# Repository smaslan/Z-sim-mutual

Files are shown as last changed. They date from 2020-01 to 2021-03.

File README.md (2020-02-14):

# Capacitive Reactance Simulator Based on Mutual Inductor

This project is simple simulator of capacitive rectance based on a mutual inductor.
It is just a first proof of concept prototype not inteded for direct production/replication.
See DOC for known issues and more details.

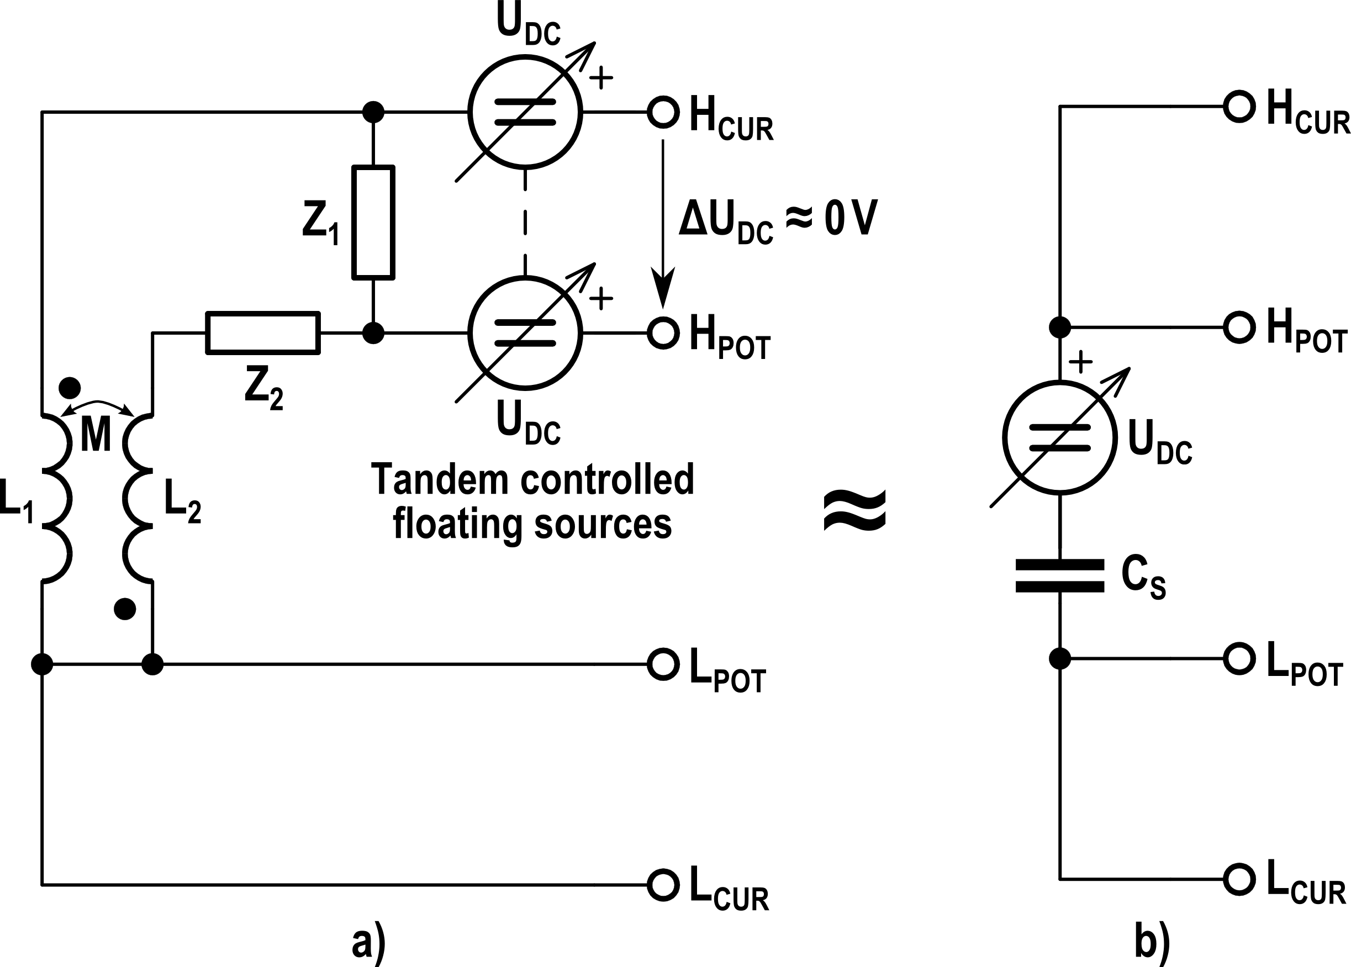
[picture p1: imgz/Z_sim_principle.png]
Z-sim-mutual


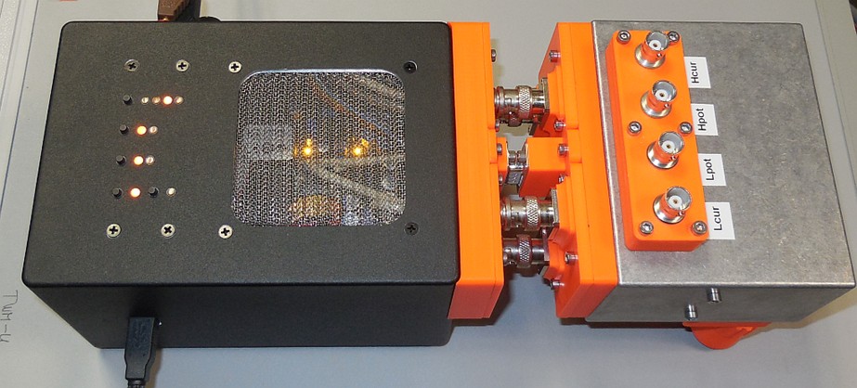
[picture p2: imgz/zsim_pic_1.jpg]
Protoype


## License
The HW design is distributed under [Cern OHL license V1.2](./cern_ohl_v_1_2.pdf). 

## Acknowledgment
Presented standard design was co-developed in scope of the [EMPIR](http://msu.euramet.org/calls.html) 
project [LiBforSecUse (17IND10)](https://www.ptb.de/empir2018/libforsecuse/home/).
The project received funding from the EMPIR programme co-financed by the Participating States 
and from the European Union's Horizon 2020 research and innovation programme.

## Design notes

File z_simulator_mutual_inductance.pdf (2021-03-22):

Mutual inductance based impedance simulator

EMPIR project report: LiBforSecUse, activity A1.1.4

Stanislav Mašláň, smaslan@cmi.cz, Czech Metrology Institute, 2021-03-22

Following document briefly describes experimental design of capacitive reactance simulator based on mutual inductance. Additional details are shown in Imeko paper [3]. The simulator is designed for calibration of battery impedance spectroscopy analysers (EIS).

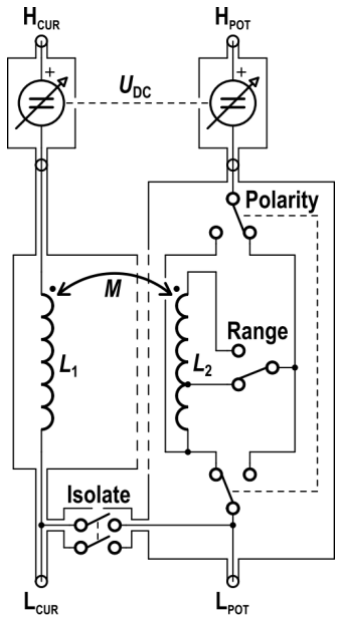
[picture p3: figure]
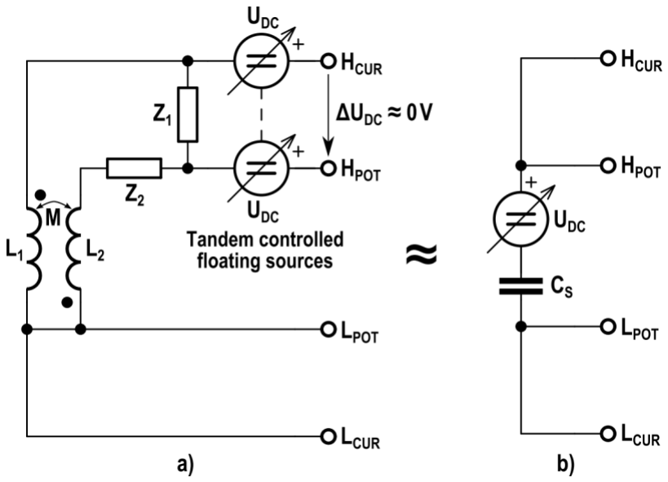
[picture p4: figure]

Figure 1: Principle of capacitance simulator based on mutual inductance (Left), full coaxial connection (Right).

The goal of the design was to achieve large capacitive reactance with simulation of DC bias voltage roughly equal to lithium cell (around 4V). The standard must be able to withstand measurement current at least 1A AC and 1A DC (2.5A peak current in both polarities).
One of the simple ways of simulating reactance is mutual inductor which can be easily designed to exhibit mutual inductances in order of nanohenry to microhenry and to be able to carry high measurement currents. If the secondary winding polarity is inverted, the apparent four terminal impedance will appear as capacitive reactance to the EIS. The basic concept is shown in Figure 1. Impedances Z1 and Z2 can be used to fine tune the apparent impedance, however they are not necessary.

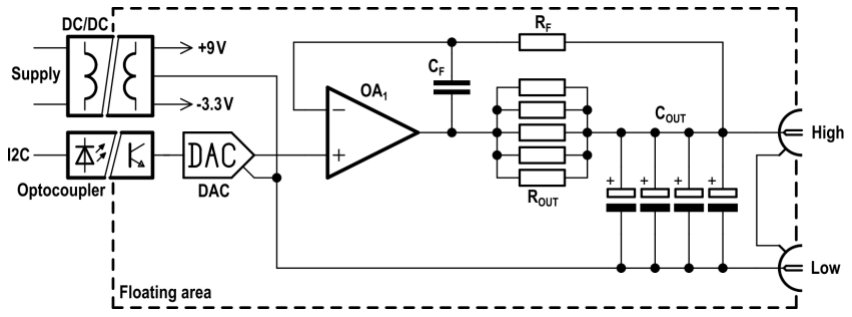
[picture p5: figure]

Figure 2: Principle of DC bias generator.

The challenging part of the design is however introduction of the DC bias voltage. It is not possible to simply insert high power DC source in series with mutual inductor, because its internal impedance would destroy properties of the impedance. It is also not reasonable to insert it just into the potential terminal, because then the EIS meter will see DC voltage between its Hcur and Hpot terminals. It may lead to fail indication or even damage of the EIS. So an alternative solution shown in Figure 1 was chosen. Two tandem controlled sources were used. One, high power floating DC source capable to withstand the measurement current is connected in series with the Hcur terminal. This source does not have to be very accurate. A second floating DC source is placed in series with the Hpot terminal. This source carries almost no current, but should be accurate and low noise. Both sources are set to identical voltage, so the EIS meter will see near zero voltage difference between Hcur and Hpot terminals and at the same time will see necessary DC bias of the impedance.

Design of DC bias source

Circuit design of first prototype is shown in Figure 3 or see GitHub source files [1]. Evidently the only complicated part of the design is the DC bias source. Both DC sources must be floating. For purposes of first prototype this was solved by using DC/DC converters. The current DC bias is supplied from a pair of 9V and 3V3 converters. This asymmetric supply was chosen to minimize power dissipation as the DC voltage range is 0 to 5V and the power opamp OPA548 needs at least some 3V reserve. The DC/DC converters outputs are filtered by low-ESR polymer caps. Care must be taken to not exceed maximum filter capacitance for particular converter to prevent regulator instability. The controlled DC source is based on power opamp OPA548. It is equipped by stabilizing network and the output is filtered by low-ESR capacitors. The opamp feedback is providing low output impedance for low frequencies, whereas the large output capacitance is providing low impedance for higher frequencies. The voltage of this source is generated by 12bit DAC connected via isolated I2C bus. Zero and gain are set by two trimmers. The whole source can be disabled by DC/DC converter enable inputs and in that case a pair of parallel latching relays bypasses the output of the source.

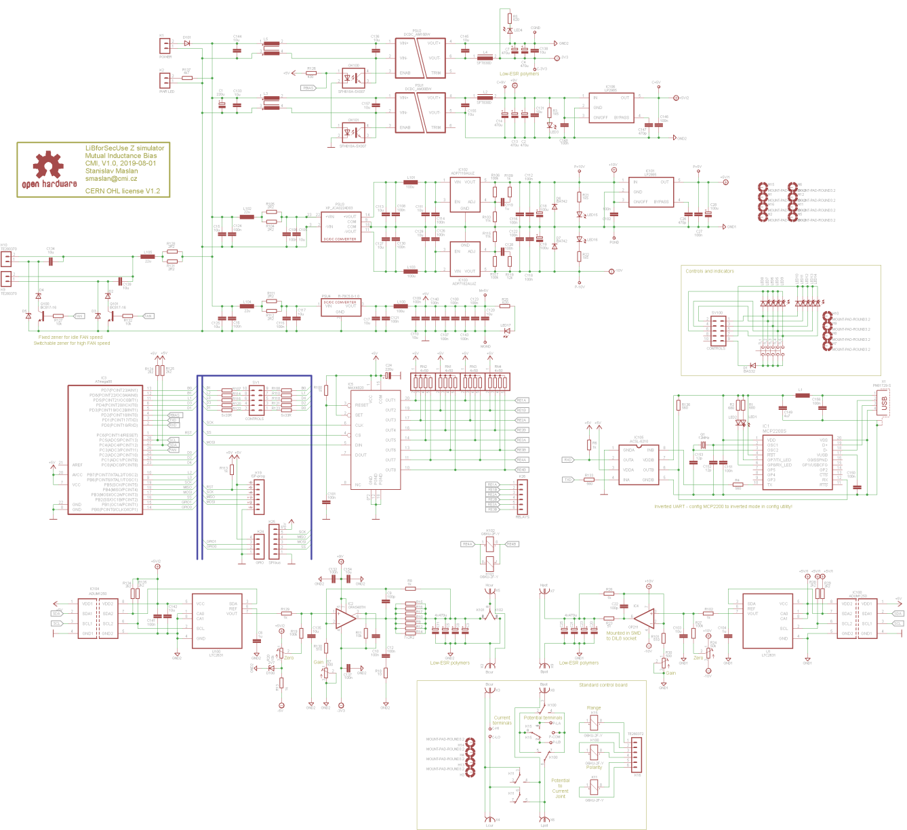
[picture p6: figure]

Figure 3: Circuit diagram of impedance simulator prototype.

The second source inserted to the potential terminals is of similar concept except it is supplied from low noise DC/DC converter with low noise LDO regulators and uses low power opamp OP211. Its output is also equipped by stabilizing network and the opamp and stabilizing network components must be chosen so it is stable with large output capacitance.
The standard itself (mutual inductor) is placed in separate box. It is connected via additional board with few latching relays that enables switching the polarity and range of the mutual inductor.
The whole unit is controlled by microcontroller AVR ATmega88. It is equipped by simple user interface with buttons and LED diodes and also it is connected to USB-UART converter MCP2200 for remote control. Note the MCP2200 is connected via optoisolator which inverts UART polarity, so MCP2200 configuration utility must be used to invert polarity of UART outputs.
The unit contains electronically switchable fan outputs with regulation of speed using Zener diodes. One diode is intended to be used for idle speed and the other switchable for high speed when current path DC bias is enabled.

Construction notes

Board drawings are shown in Figure 4 and Figure 5 and at GitHub [1]. The DC source unit was designed to fit in Hammond die cast box HM-1550F. The power opamp OPA548 is soldered from bottom of the PCB, so its terminals must be bent up from the heatsink. It is screwed to the heatsink which is screwed from bottom of the PCB. The heatsink must be able to cool full power which is up to some 23W, so a fans are intended to be used.
The standard itself was placed to another box Eddyston 26908PSLA together with the relay board. Both boxes are connected via BNC connectors and Cannon 9 connector. The output terminals to the EIS are placed at the standard box. The connection between the two boxes is made using 3D printed components which are also available at GitHub [1]. Note there are no male BNCs with crimping terminals, so a flange types were used and they are connected to the coaxes via brass foil screwed to them.
The mutual inductor itself is constructed as air-core toroid so most of the field is contained. Therefore, it is not affected by near metallic objects and exhibits no significant non-linearities. The winding is made from multifilar rope of copper enamelled wires. 10 wires from the rope are connected in parallel and used as primary. The remaining 10 are connected in series to form secondary. The unit has two ranges, so one range is full 10 loops and the other range is connected to a first tap. The core of the toroid is 3D printed. See GitHub for model.

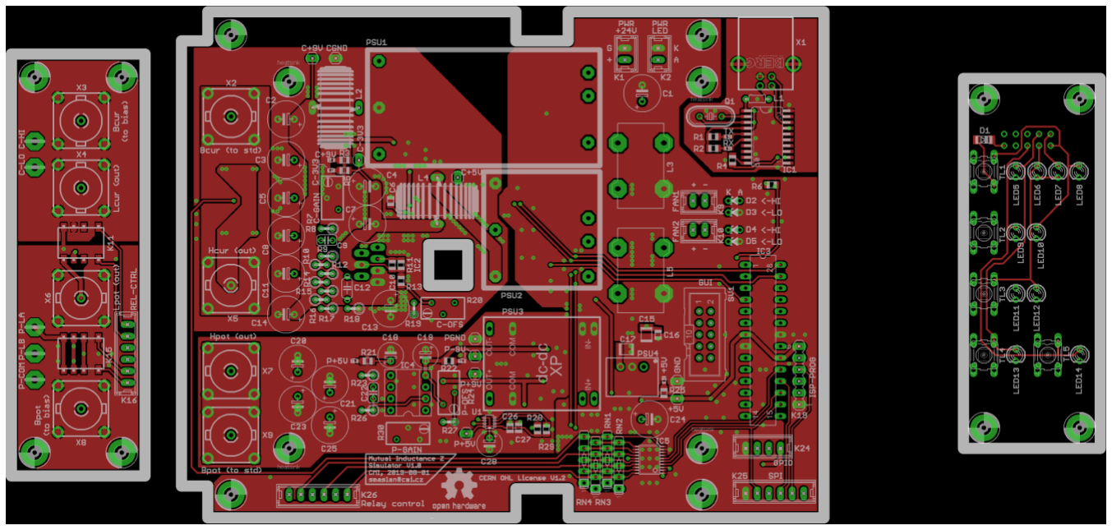
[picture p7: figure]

Figure 4: Top layer of PCB.

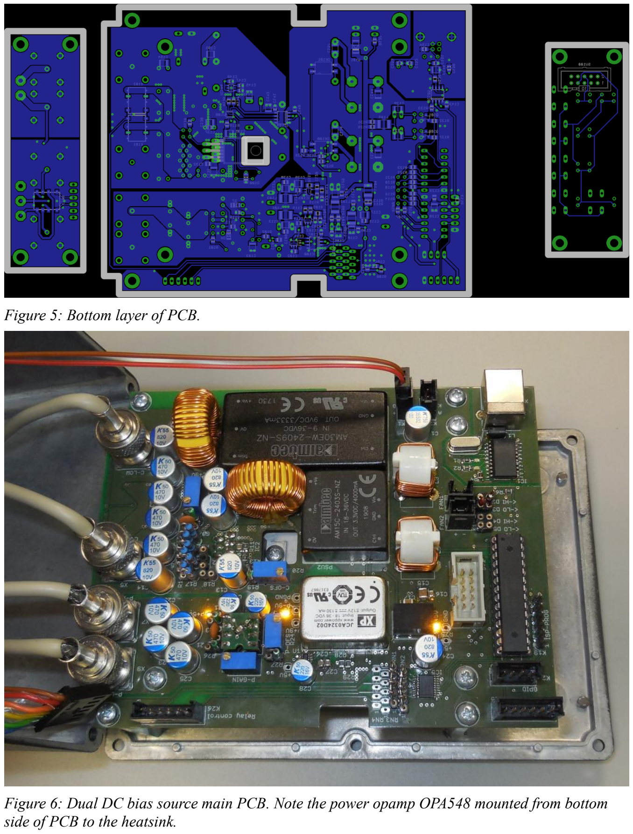
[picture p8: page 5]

Figure 5: Bottom layer of PCB.

Figure 6: Dual DC bias source main PCB. Note the power opamp OPA548 mounted from bottom side of PCB to the heatsink.

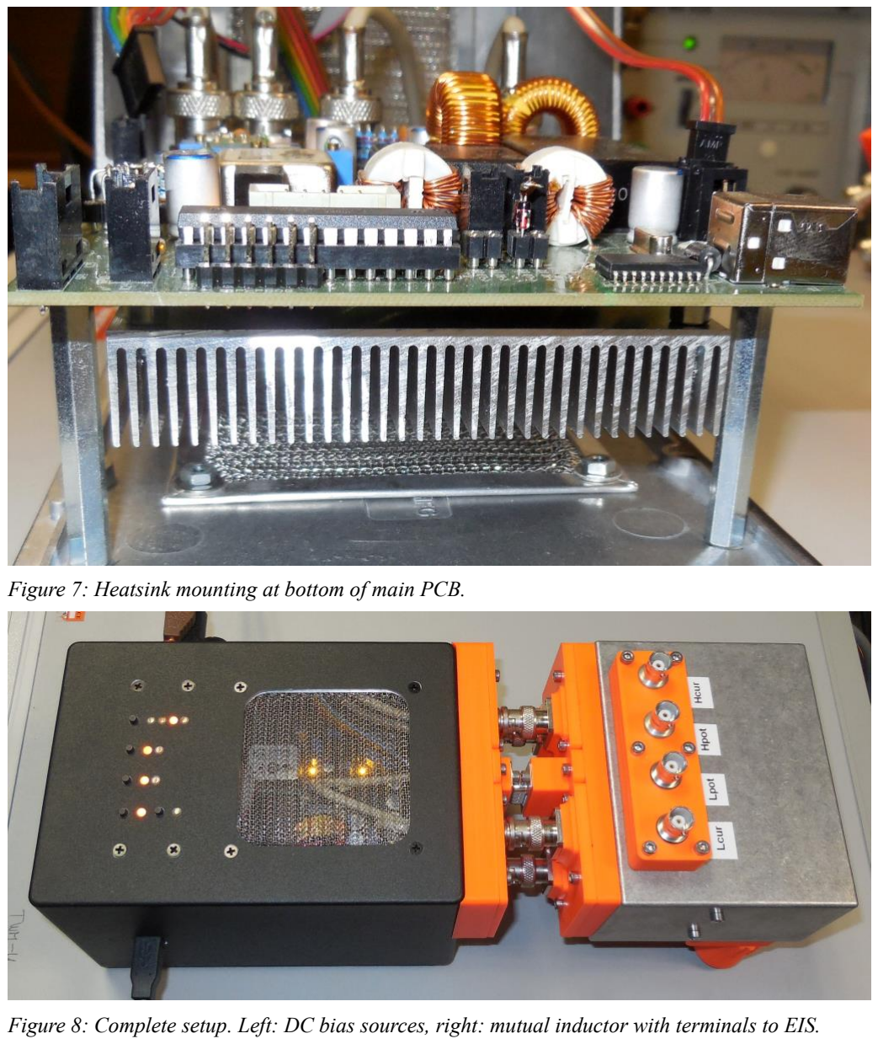
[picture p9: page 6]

Figure 7: Heatsink mounting at bottom of main PCB.

Figure 8: Complete setup. Left: DC bias sources, right: mutual inductor with terminals to EIS.

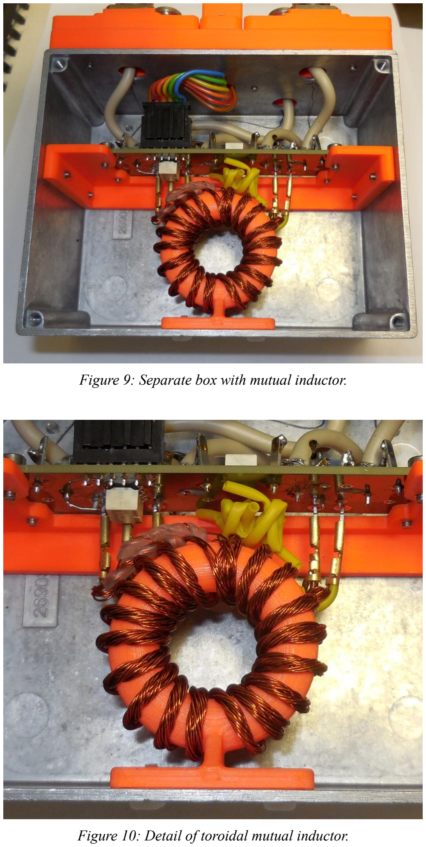
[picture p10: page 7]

Figure 9: Separate box with mutual inductor.

Figure 10: Detail of toroidal mutual inductor.

Firmware

The firmware for the MCU is available at GitHub. It was made in AVR Studio 4 with AVRGCC compiler. Note the unit expects operation from internal RC oscillator set to 1 MHz which is default fuse setting, so no fuses should be modified. Programming is possible only via ISP interface. It is recommended to supply the unit from regulated PSU just in case the latching relays controller is “confused” during the programming via the shared SPI interface.

Remote operation

Remote interface is set to baud rate of 9600bd, 1 stop, no parity and no flow control. It implements few basic SCPI style commands. All commands and answers are terminated by LF. Chaining by semicolon is supported. Do not exceed 127 characters in long chained commands. Errors are returned using common SYST:ERR? command.

Command | Description
*IDN? | Returns identification string.
*RST | Resets device.
*OPC? | Returns +1 when device is ready.
SYST:ERR? | Returns last error (buffer can take only one error).
SYST:BOOT <passcode> | Invoke bootloader. Passcode = 17IND10. This command will jump to AVR microcontroller boot section as set by fusebits. If no bootloader was programmed, it will only reset device. See text for further details.
FAN <speed> | Sets FAN speed to HI/HIGH or LO/LOW (default powerup is LO).
MODE <mode> | Sets polarity of the secondary coil to „CAP“ or „IND“.
RANGE <range> | Sets range to „1“ or „2“.
COMMON:STATE <state> | Sets state of relay that connects current and potential terminals. Valid values are „0“, „OFF“ or „1“, „ON“.
POWER:STATE <state> | Enables or disables current DC bias source. Valid values are „0“, „OFF“ or „1“, „ON“.
BIAS:VOLT <level> | Sets both sources to identical level in millivolts. Note <level> is integer.
BIAS:POT:VOLT <level> | Sets level of potential DC bias source in millivolts. Note <level> is integer.
BIAS:PWR:VOLT <level> | Sets level of current terminal DC bias source in millivolts. Note <level> is integer.

Bootloader

Project also contains simple bootloader made in assembly code. It fits to last 512 Bytes of AVR FLASH memory. So bootsize fuse bits should be set accordingly (BOOTSZ1 = 1, BOOTSZ0 = 0). Eventually BOOTRST = 0 will make AVR jump to bootsection after powerup. For details see either bootloader ASM code or Octave bootloader m-file (both attached at GitHub [1]).

Known issues

The simulator is just a proof-of-concept prototype, so there are few problems that must be addressed for final version. First, the chosen DACs exhibit relatively high noise. They should be replaced by low noise types (eg AD5781) or maybe at least equipped by low noise references.
Second, the DC/DC converters produce considerable common mode noise and also have large mutual capacitance. Both problems can be addressed by active guarding. The simplest way would be to connect two DC/DC converters in series and supply the join between them from a guard buffer. That will break capacitance to supply and should also reduce the noise. At the same time the guard buffer should guard the whole DC source part of the PCB and in case of the current path source it should also guard the heatsink somehow to reduce the capacitance as much as possible.
FW should be improved to be more SCPI compliant. Especially chaining commands by semicolon should be implemented.

Usage

Power supply:
The unit is designed for supply source 24 V, 1 A. Actual consumption depends on measurement current and will be much lower when current path bias source is disabled.

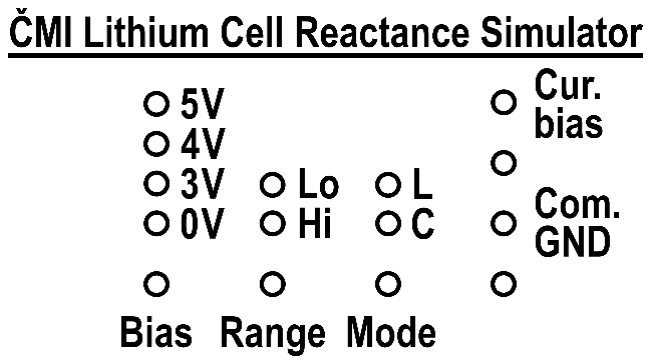
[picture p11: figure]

Figure 11: Controls of the prototype.

Bias control:
Front panel of prototype is shown in Figure 11. Pressing button “Bias” will cycle preset values of DC bias voltage to the shown levels. It is recommended to cycle through once around before connecting the unit to RLC meters just in case there is random voltage after power up glitch! When the “Cur. bias” LED is not lid, the current path bias source is inactive and shorted. Only the potential path bias source is driven, so the “Bias” button affects only potential path. When current path bias source is to be used, press button “Cur. bias”. LED will be lid and the simulator will be ready in few seconds once its internal DCDC converters charges filtration capacitors. When “Cur. bias” is lid, the “Bias” button will control both potential and current path bias sources and sets them to the same level.

Current-potential joint control:
Button “Com. GND” will connect potential and current paths together at low side. Always use this option for RLC/EIS meters, because otherwise they will not be able to balance! Not enabled “Com. GND” is suitable only for some specialized sampling bridges where balancing is not used, but it will change value of simulated impedance slightly.

Range and mode control:
Remaining controls are “Range” and “Mode”. The “Range” changes tap of the coil in the standard itself. Prototype contains coil with ranges roughly 350 nH “Lo” and 3.5 µH “Hi”. Button “Mode” changes polarity of the secondary coil to simulate either inductive reactance “L” or capacitive reactance “C”. The reactance will change sign for both real and imaginary components, so do not be surprised the EIS meter will show negative loss tangent (or ESR) for capacitive mode.

Remote control:
As described above, the simulator has interface for remote control using few SCPI commands. Their function is equivalent to the buttons with one exception. It is possible to control independently potential and current path DC bias levels and it is possible to set any DC bias between 0 and 5 V. In that case LEDs “0V” and “5V” will be lid together to indicate remotely set levels. Pressing “Bias” will cancel this mode and set common level to both sources again. FAN speed can be increased which may be good idea when using current bias at full current.

Connection to RLC meters:
The unit was designed mainly for testing impedance analyzers for battery impedance spectroscopy (EIS). This simulator uses topology where bias voltage generators will not affect simulated impedance, so it offers unique possibility to check if the EIS meter is insensitive to applied bias. However, both current and potential sources can deliver significant power and both sources have large decoupling capacitances, so when connected to RLC meters that cannot stand external DC bias, such as Keysight E4980A, it may easily damage it! So be very cautious before connecting it to any RLC meter. Always check user manual. Some RLC meters may support external DC bias with external adapters, some may support it directly. It was tested directly with E4980A without any adapters, but before that it was necessary to disable “Cur. bias”, set “Bias” to “0V” and use multimeter to check there is actually no significant voltage between live conductors of potential and current BNCs! There will be always few millivolts, but that should be ok for most RLC meters.
The simulator uses DCDC converters which inevitably produces considerable capacitive currents and EMC. Therefore, it is good idea to connect the simulator via coaxial cables equipped by coaxial chokes to reduce noise in the measurement. Four 500 mH chokes were used at ČMI for this purpose. Also connect negative power supply input to ground terminal of the RLC meter. This will improve the noise levels.

References

[1] GitHub, Z-sim-mutual, url: https://github.com/smaslan/Z-sim-mutual
[2] EURAMET, EMPIR Lithium Batteries for Second Life Applications, url: https://www.ptb.de/empir2018/de/libforsecuse/project/overview/
[3] Stanislav Mašláň, “High capacitance simulation using mutual inductors”, 24th IMEKO TC4 International Symposium, Palermo, Italy, September 14-16, 2020.

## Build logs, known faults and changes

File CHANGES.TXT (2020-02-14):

List of changes:
----------------
V1.0, 2020-02-14 - First release.

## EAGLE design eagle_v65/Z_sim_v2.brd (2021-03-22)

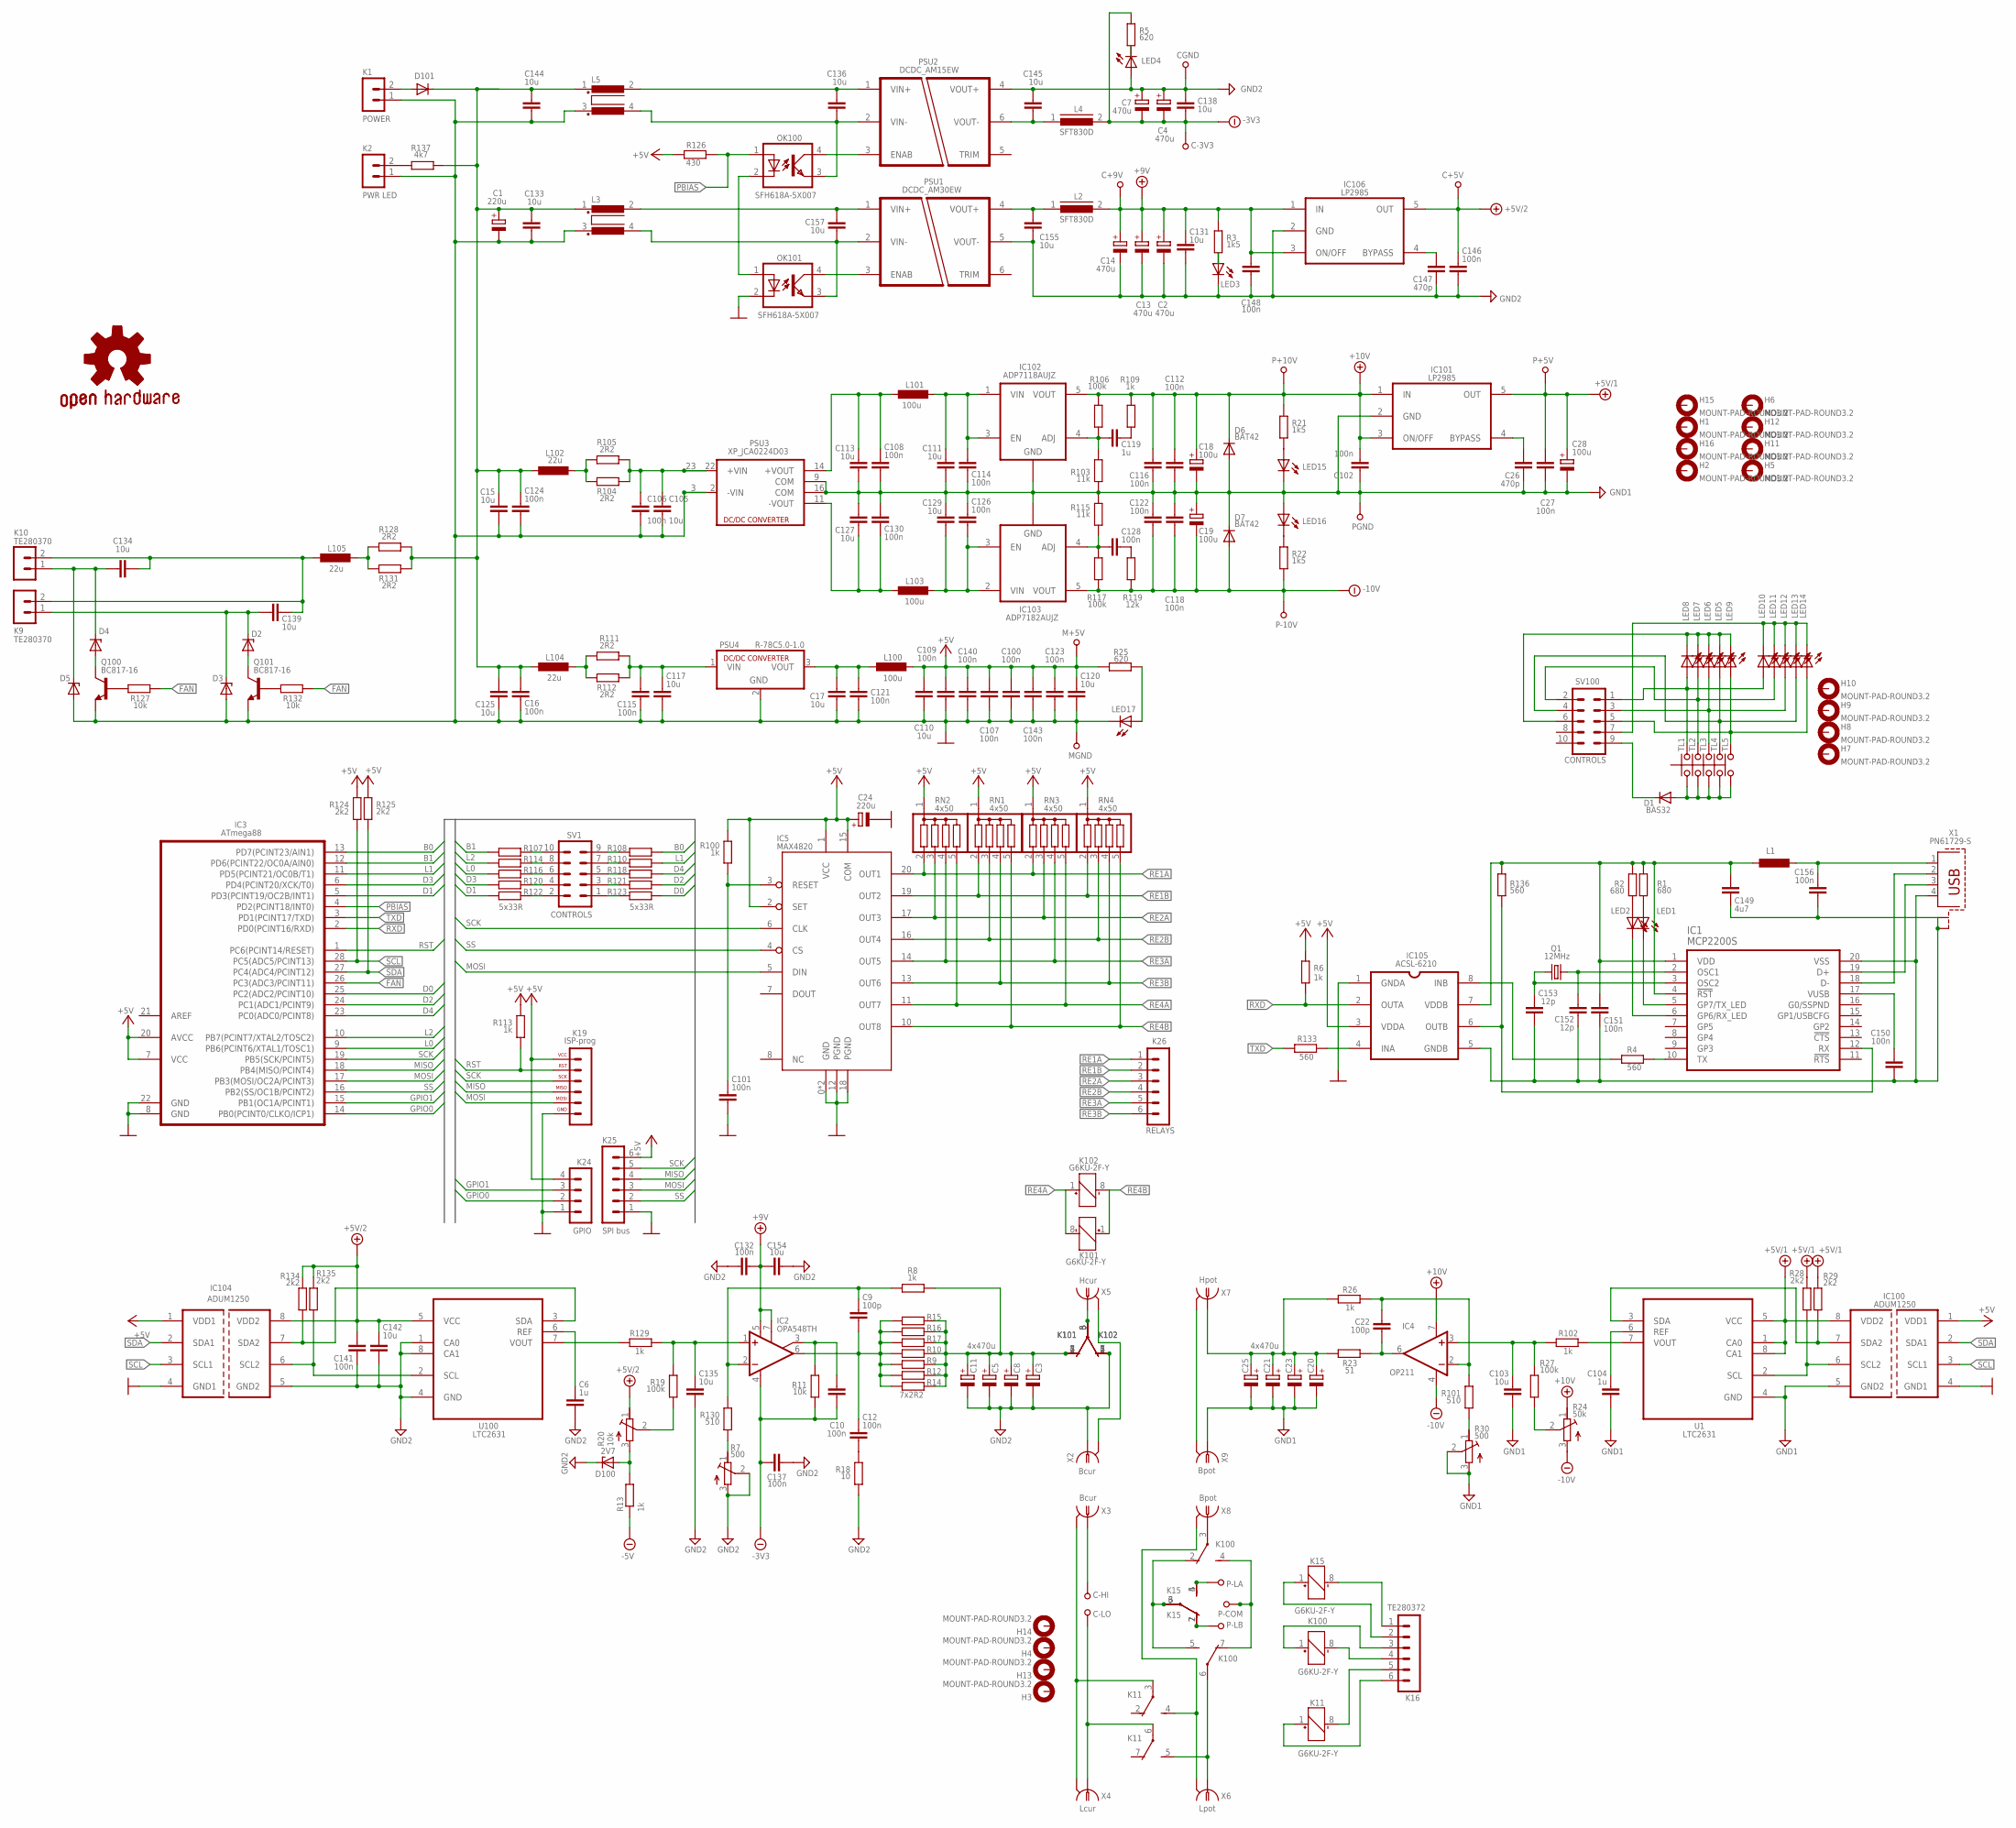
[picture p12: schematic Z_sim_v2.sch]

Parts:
C1, C24: 220u; E3,5-8
C2, C4, C7, C13, C14: 470u; E3,5-8
C3, C5, C8, C20, C21, C23: CPOL-EUE3.5-8; E3,5-8
C6, C104, C119: 1u; X0805
C9, C22: 100p; C025-024X044
C10, C16, C27, C100, C101, C102, C106, C107, C108, C109, C112, C114, C115, C116, C118, C121, C122, C123, C124, C126, C128, C130, C132, C137, C140, C141, C143, C146, C148, C150, C151, C156: 100n; X0805
C11, C25: 4x470u; E3,5-8
C12: 100n; C050-024X044
C15, C17, C103, C105, C110, C111, C113, C117, C120, C125, C127, C129, C131, C133, C134, C135, C136, C138, C139, C142, C144, C145, C154, C155, C157: 10u; C1210K
C18, C19, C28: 100u; E2,5-6
C26, C147: 470p; X0805
C149: 4u7; C1210K
C152, C153: 12p; X0805
C+5V, C+9V: SPL; SP
C-3V3: SPL; SP
C-HI: FAST28R; FAST28_R
C-LO: FAST28R; FAST28_R
CGND: SPL; SP
D1: BAS32; SOD80C
D2, D3, D4, D5: ZENER-DIODEZD-2.5; ZDIO-2.5
D6, D7: BAT42; SOD80C
D100: 2V7; SOD80C
D101: DIODE-MELF-MLL41; MELF-MLL41
GOLD_ORB_SM1: OSHWLOGO_GOLD_ORB_MED; OSHW1
H1, H2, H3, H4, H5, H6, H7, H8, H9, H10, H11, H12, H13, H14, H15, H16: MOUNT-PAD-ROUND3.2; 3,2-PAD
IC1: MCP2200S; SOIC20W
IC2: OPA548TH; TO220-7H
IC3: ATmega88; DIL28
IC4: OP211; DIL08
IC5: MAX4820; TSSOP20
IC100, IC104: ADUM1250; SO8
IC101, IC106: LP2985; SOT23-5
IC102: ADP7118AUJZ; SOT23-5
IC103: ADP7182AUJZ; SOT23-5
IC105: ACSL-6210; SO8
K1: POWER; TE280370
K2: PWR LED; TE280370
K9, K10: TE280370
K11, K15, K100, K101, K102: G6KU-2F-Y
K16: TE280372
K19: ISP-prog; SIL6
K24: GPIO; TE280371
K25: SPI bus; TE280372
K26: RELAYS; TE280372
L1: L-EU0204/5; 0204/5
L2, L4: SFT830D
L3, L5: R1405UB1/2; B1/2
L100, L101, L103: 100u; L1812
L102, L104, L105: 22u; L1812
LED1, LED2, LED3, LED4, LED15, LED16, LED17: LEDCHIP-LED0603; CHIP-LED0603
LED5, LED6, LED7, LED8, LED9, LED10, LED11, LED12, LED13, LED14: LED3MM
M+5V: SPL; SP
MGND: SPL; SP
OK100, OK101: SFH618A-5X007; SMD4-7
P+5V, P+10V: SPL; SP
P-10V: SPL; SP
P-COM: FAST28R; FAST28_R
P-LA: FAST28R; FAST28_R
P-LB: FAST28R; FAST28_R
PGND: SPL; SP
PSU1: DCDC_AM30EW
PSU2: DCDC_AM15EW
PSU3: XP_JCA0224D03; DCDC_XP_JCA_SYMOUT
PSU4: R-78C5.0-1.0; SIP3
Q1: 12MHz; HC49/S
Q100, Q101: BC817-16; SOT23-BEC
R1, R2: 680; X0805
R3, R21, R22: 1k5; X0805
R4, R133, R136: 560; X0805
R5, R25: 620; X0805
R6, R13, R100, R102, R109, R113, R129: 1k; X0805
R7, R30: 500; RTRIMT93YB
R8, R26: 1k; 0207/2V
R9, R10, R14, R15, R16, R17: R-EU_0207/2V; 0207/2V
R11, R127, R132: 10k; X0805
R12: 7x2R2; 0207/2V
R18: 10; 0207/2V
R19, R27: 100k; 0204V
R20: 10k; RTRIMT93YB
R23: 51; 0207/2V
R24: 50k; RTRIMT93YB
R28, R29, R124, R125, R134, R135: 2k2; X0805
R101, R130: 510; X0805
R103, R115: 11k; X0805
R104, R105, R111, R112, R128, R131: 2R2; X0805
R106, R117: 100k; X0805
R107, R123: 5x33R; X0805
R108, R110, R114, R116, R118, R120, R121, R122: R-EU_X0805; X0805
R119: 12k; X0805
R126: 430; X0805
R137: 4k7; X0805
RN1, RN2, RN3, RN4: 4x50; SIL5
SV1, SV100: CONTROLS; ML10
TL1, TL2, TL3, TL4, TL5: CUDL1_A; CUDL1
U1, U100: LTC2631; SOT65P280X100-8N
X1: PN61729-S
X2, X3: Bcur; A1944
X4: Lcur; A1944
X5: Hcur; A1944
X6: Lpot; A1944
X7: Hpot; A1944
X8, X9: Bpot; A1944

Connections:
+5V: C24.+, C100.P$1 (1), C107.P$1 (1), C109.P$1 (1), C110.1, C120.1, C123.P$1 (1), C140.P$1 (1), C143.P$1 (1), IC3.7 (VCC), IC3.20 (AVCC), IC5.1 (VCC), IC5.2 (SET), IC5.15 (COM), IC100.1 (VDD1), IC104.1 (VDD1), IC105.3 (VDDA), K19.6, K24.4, K25.6, L100.2, M+5V.1, R6.P$2 (2), R25.P$2 (2), R100.P$2 (2), R113.P$2 (2), R124.P$2 (2), R125.P$2 (2), R126.P$2 (2), RN1.1, RN2.1, RN3.1, RN4.1
+5V/1: C27.P$2 (2), C28.+, IC100.8 (VDD2), IC101.5 (OUT), P+5V.1, R28.P$2 (2), R29.P$2 (2), U1.1 (CA0), U1.5 (VCC), U1.8 (CA1)
+5V/2: C141.P$1 (1), C142.1, C146.P$2 (2), C+5V.1, IC104.8 (VDD2), IC106.5 (OUT), R20.1 (E), R134.P$2 (2), R135.P$2 (2), U100.5 (VCC)
+9V: C2.+, C13.+, C14.+, C131.1, C132.P$2 (2), C148.P$2 (2), C154.1, C+9V.1, IC2.5 (V+), IC2.7 (E/S), IC106.1 (IN), IC106.3 (ON/OFF), L2.2, R3.P$2 (2)
+10V: C18.+, C102.P$2 (2), C112.P$1 (1), C116.P$1 (1), D6.C, IC4.7 (V+), IC101.1 (IN), IC101.3 (ON/OFF), IC102.5 (VOUT), P+10V.1, R21.P$2 (2), R24.1 (E), R106.P$2 (2), R109.P$1 (1)
-5V: C4.-, C7.-, C10.P$2 (2), C137.P$1 (1), C138.2, C-3V3.1, IC2.4 (V-), L4.2, R5.P$2 (2), R11.P$2 (2), R13.P$1 (1)
-10V: C19.-, C118.P$2 (2), C122.P$2 (2), D7.A, IC4.4 (V-), IC103.5 (VOUT), P-10V.1, R22.P$2 (2), R24.3 (A), R117.P$1 (1), R119.P$2 (2)
B0: IC3.13 (PD7(PCINT23/AIN1)), R108.P$2 (2)
B1: IC3.12 (PD6(PCINT22/OC0A/AIN0)), R107.P$1 (1)
D0: IC3.25 (PC2(ADC2/PCINT10)), R123.P$2 (2)
D1: IC3.5 (PD3(PCINT19/OC2B/INT1)), R122.P$1 (1)
D2: IC3.24 (PC1(ADC1/PCINT9)), R121.P$2 (2)
D3: IC3.6 (PD4(PCINT20/XCK/T0)), R120.P$1 (1)
D4: IC3.23 (PC0(ADC0/PCINT8)), R118.P$2 (2)
FAN: IC3.26 (PC3(ADC3/PCINT11)), R127.P$1 (1), R132.P$1 (1)
GND: C1.-, C15.2, C16.P$2 (2), C17.2, C24.-, C100.P$2 (2), C101.P$2 (2), C105.2, C106.P$2 (2), C107.P$2 (2), C109.P$2 (2), C110.2, C115.P$2 (2), C117.2, C120.2, C121.P$2 (2), C123.P$2 (2), C124.P$2 (2), C125.2, C133.2, C140.P$2 (2), C143.P$2 (2), C144.2, D3.A, D5.A, IC3.8 (GND), IC3.22 (GND), IC5.0 (GND), IC5.9 (GND), IC5.12 (PGND), IC5.18 (PGND), IC100.4 (GND1), IC104.4 (GND1), IC105.1 (GNDA), K1.1, K2.1, K19.1, K24.1, K25.1, L3.3, L5.3, LED17.C, MGND.1, OK101.2 (C), PSU3.2 (-VIN), PSU3.3 (-VIN1), PSU4.2 (GND), Q100.E, Q101.E
GND1: C18.-, C19.+, C20.-, C21.-, C23.-, C25.-, C26.P$2 (2), C27.P$1 (1), C28.-, C102.P$1 (1), C103.2, C104.P$2 (2), C108.P$2 (2), C111.2, C112.P$2 (2), C113.2, C114.P$2 (2), C116.P$2 (2), C118.P$1 (1), C122.P$1 (1), C126.P$1 (1), C127.1, C129.1, C130.P$1 (1), D6.A, D7.C, IC100.5 (GND2), IC101.2 (GND), IC102.2 (GND), IC103.1 (GND), LED15.C, LED16.A, PGND.1, PSU3.9 (COM), PSU3.16 (COM), R30.2 (S), R30.3 (A), R103.P$1 (1), R115.P$2 (2), U1.4 (GND), X9.1
GND2: C2.-, C3.-, C4.+, C5.-, C6.P$2 (2), C7.+, C8.-, C11.-, C13.-, C14.-, C131.2, C132.P$1 (1), C135.2, C137.P$2 (2), C138.1, C141.P$2 (2), C142.2, C145.1, C146.P$1 (1), C147.P$2 (2), C148.P$1 (1), C154.2, C155.2, CGND.1, D100.C, IC104.5 (GND2), IC106.2 (GND), K101.4 (S), K101.5 (S), K102.2 (O), K102.7 (O), LED3.C, LED4.A, PSU1.5 (VOUT-), PSU2.4 (VOUT+), R7.2 (S), R7.3 (A), R18.1, U100.1 (CA0), U100.4 (GND), U100.8 (CA1), X2.1
GPIO0: IC3.14 (PB0(PCINT0/CLKO/ICP1)), K24.2
GPIO1: IC3.15 (PB1(OC1A/PCINT1)), K24.3
L0: IC3.9 (PB6(PCINT6/XTAL1/TOSC1)), R116.P$1 (1)
L1: IC3.11 (PD5(PCINT21/OC0B/T1)), R110.P$2 (2)
L2: IC3.10 (PB7(PCINT7/XTAL2/TOSC2)), R114.P$1 (1)
MISO: IC3.18 (PB4(MISO/PCINT4)), K19.3, K25.4
MOSI: IC3.17 (PB3(MOSI/OC2A/PCINT3)), IC5.5 (DIN), K19.2, K25.3
unnamed: C10.P$1 (1), IC2.3 (ILIM), R11.P$1 (1)
unnamed: OK100.4 (COL), PSU2.3 (ENAB)
unnamed: C135.1, IC2.1 (+IN), R19.2, R129.P$2 (2)
unnamed: C136.1, L5.2, PSU2.1 (VIN+)
unnamed: R19.1, R20.2 (S)
unnamed: C3.+, C5.+, C8.+, C11.+, K101.2 (O), K101.7 (O), K102.4 (S), K102.5 (S), R8.2, R9.2, R10.1, R12.2, R14.1, R15.2, R16.1, R17.2
unnamed: C12.2, R18.2
unnamed: C136.2, L5.4, OK100.3 (EMIT), PSU2.2 (VIN-)
unnamed: R129.P$1 (1), U100.7 (VOUT)
unnamed: C9.1, IC2.2 (-IN), R8.1, R130.P$2 (2)
unnamed: R7.1 (E), R130.P$1 (1)
unnamed: D100.A, R13.P$2 (2), R20.3 (A)
unnamed: C157.1, L3.2, PSU1.1 (VIN+)
unnamed: C157.2, L3.4, OK101.3 (EMIT), PSU1.2 (VIN-)
unnamed: K101.3, K101.6, K102.3, K102.6, X5.1
unnamed: C147.P$1 (1), IC106.4 (BYPASS)
unnamed: IC105.4 (INA), R133.P$2 (2)
unnamed: OK101.4 (COL), PSU1.3 (ENAB)
unnamed: OK100.2 (C), OK101.1 (A)
unnamed: C6.P$1 (1), U100.6 (REF)
unnamed: C139.1, D2.C, D3.C, K9.1
unnamed: C111.1, C114.P$1 (1), IC102.1 (VIN), IC102.3 (EN), L101.2
unnamed: IC104.6 (SCL2), R135.P$1 (1), U100.2 (SCL)
unnamed: IC104.7 (SDA2), R134.P$1 (1), U100.3 (SDA)
unnamed: C103.1, IC4.3 (+IN), R27.2, R102.P$2 (2)
unnamed: R24.2 (S), R27.1
unnamed: R102.P$1 (1), U1.7 (VOUT)
unnamed: C22.2, IC4.6 (OUT), R23.1
unnamed: C104.P$1 (1), U1.6 (REF)
unnamed: IC100.6 (SCL2), R28.P$1 (1), U1.2 (SCL)
unnamed: IC100.7 (SDA2), R29.P$1 (1), U1.3 (SDA)
unnamed: C126.P$2 (2), C129.2, IC103.2 (VIN), IC103.3 (EN), L103.2
unnamed: C127.2, C130.P$2 (2), L103.1, PSU3.11 (-VOUT)
unnamed: C108.P$1 (1), C113.1, L101.1, PSU3.14 (+VOUT)
unnamed: C20.+, C21.+, C23.+, C25.+, R23.2, R26.2, X7.1
unnamed: C128.P$2 (2), IC103.4 (ADJ), R115.P$1 (1), R117.P$2 (2)
unnamed: C128.P$1 (1), R119.P$1 (1)
unnamed: C119.P$2 (2), IC102.4 (ADJ), R103.P$2 (2), R106.P$1 (1)
unnamed: C119.P$1 (1), R109.P$2 (2)
unnamed: D2.A, Q101.C
unnamed: L102.2, R104.P$1 (1), R105.P$1 (1)
unnamed: C105.1, C106.P$1 (1), PSU3.22 (+VIN), PSU3.23 (+VIN1), R104.P$2 (2), R105.P$2 (2)
unnamed: C22.1, IC4.2 (-IN), R26.1, R101.P$2 (2)
unnamed: R30.1 (E), R101.P$1 (1)
unnamed: C134.1, D4.C, D5.C, K10.1
unnamed: C26.P$1 (1), IC101.4 (BYPASS)
unnamed: X7.2, X7.3 (2), X7.4 (2), X7.5 (2), X9.2, X9.3 (2), X9.4 (2), X9.5 (2)
unnamed: Q101.B, R132.P$2 (2)
unnamed: C115.P$1 (1), C117.1, PSU4.1 (VIN), R111.P$2 (2), R112.P$2 (2)
unnamed: D101.A, K1.2
unnamed: L104.2, R111.P$1 (1), R112.P$1 (1)
unnamed: C9.2, C12.1, IC2.6 (OUT), R9.1, R10.2, R12.1, R14.2, R15.1, R16.2, R17.1
unnamed: C17.1, C121.P$1 (1), L100.1, PSU4.3 (VOUT)
unnamed: X2.2, X2.3 (2), X2.4 (2), X2.5 (2), X5.2, X5.3 (2), X5.4 (2), X5.5 (2)
unnamed: C101.P$1 (1), IC5.3 (RESET), R100.P$1 (1)
unnamed: D4.A, Q100.C
unnamed: Q100.B, R127.P$2 (2)
unnamed: K2.2, R137.P$2 (2)
unnamed: R122.P$2 (2), SV1.2
unnamed: R120.P$2 (2), SV1.4
unnamed: C152.P$2 (2), IC1.2 (OSC1), Q1.2
unnamed: C153.P$2 (2), IC1.3 (OSC2), Q1.1
unnamed: C156.P$2 (2), L1.1, X1.1
unnamed: R123.P$1 (1), SV1.1
unnamed: R121.P$1 (1), SV1.3
unnamed: IC1.18 (D-), X1.2
unnamed: IC1.19 (D+), X1.3
unnamed: C150.P$2 (2), IC1.17 (VUSB)
unnamed: C149.1, C151.P$2 (2), IC1.1 (VDD), IC1.4 (!RST), IC105.7 (VDDB), L1.2, R1.P$2 (2), R2.P$2 (2), R136.P$2 (2)
unnamed: LED1.A, R1.P$1 (1)
unnamed: LED2.A, R2.P$1 (1)
unnamed: IC1.5 (GP7/TX_LED), LED1.C
unnamed: IC1.6 (GP6/RX_LED), LED2.C
unnamed: IC1.12 (RX), IC105.6 (OUTB), R136.P$1 (1)
unnamed: R118.P$1 (1), SV1.5
unnamed: IC1.10 (TX), R4.P$2 (2)
unnamed: IC105.8 (INB), R4.P$1 (1)
unnamed: C149.2, C150.P$1 (1), C151.P$1 (1), C152.P$1 (1), C153.P$1 (1), C156.P$1 (1), IC1.20 (VSS), IC105.5 (GNDB), X1.4, X1.S1, X1.S2
unnamed: R116.P$2 (2), SV1.6
unnamed: R114.P$2 (2), SV1.8
unnamed: R110.P$1 (1), SV1.7
unnamed: R107.P$2 (2), SV1.10
unnamed: R108.P$1 (1), SV1.9
unnamed: LED3.A, R3.P$1 (1)
unnamed: LED4.C, R5.P$1 (1)
unnamed: LED17.A, R25.P$1 (1)
unnamed: LED15.A, R21.P$1 (1)
unnamed: LED16.C, R22.P$1 (1)
unnamed: LED8.A, LED10.A, SV100.1, TL1.1
unnamed: LED7.A, LED11.A, SV100.2, TL2.1
unnamed: LED6.A, LED12.A, SV100.3, TL3.1
unnamed: LED5.A, LED13.A, SV100.4, TL4.1
unnamed: LED9.A, LED14.A, SV100.5, TL5.1
unnamed: K15.2 (O), K15.7 (O), P-LB.P$1
unnamed: K15.4 (S), K15.5 (S), P-LA.P$1
unnamed: D1.A, TL1.3, TL2.3, TL3.3, TL4.3, TL5.3
unnamed: D1.C, SV100.9
unnamed: LED5.K (C), LED6.K (C), LED7.K (C), LED8.K (C), LED9.K (C), SV100.6
unnamed: LED10.K (C), LED11.K (C), LED12.K (C), LED13.K (C), LED14.K (C), SV100.7
unnamed: K15.3, K15.6, K100.2 (O), K100.5 (S)
unnamed: K100.3, X8.1
unnamed: K100.4 (S), K100.7 (O), P-COM.P$1
unnamed: K16.4, K100.8 (-)
unnamed: C134.2, C139.2, K9.2, K10.2, L105.1
unnamed: K11.5 (S), K100.6, X6.1
unnamed: K11.4 (S), X6.2, X6.3 (2), X6.4 (2), X6.5 (2), X8.2, X8.3 (2), X8.4 (2), X8.5 (2)
unnamed: L105.2, R128.P$1 (1), R131.P$1 (1)
unnamed: C1.+, C15.1, C16.P$1 (1), C124.P$1 (1), C125.1, C133.1, C144.1, D101.C, L3.1, L5.1, L102.1, L104.1, R128.P$2 (2), R131.P$2 (2), R137.P$1 (1)
unnamed: C-HI.P$1, X3.1
unnamed: C-LO.P$1, K11.6, X4.1
unnamed: K11.3, X3.2, X3.3 (2), X3.4 (2), X3.5 (2), X4.2, X4.3 (2), X4.4 (2), X4.5 (2)
unnamed: K15.1 (+), K16.2
unnamed: K15.8 (-), K16.1
unnamed: K16.3, K100.1 (+)
unnamed: K11.1 (+), K16.6
unnamed: K11.8 (-), K16.5
PBIAS: IC3.4 (PD2(PCINT18/INT0)), OK100.1 (A), R126.P$1 (1)
RE1A: IC5.20 (OUT1), K26.1, RN2.2, RN3.2
RE1B: IC5.19 (OUT2), K26.2, RN1.2, RN4.2
RE2A: IC5.17 (OUT3), K26.3, RN2.3, RN3.3
RE2B: IC5.16 (OUT4), K26.4, RN1.3, RN4.3
RE3A: IC5.14 (OUT5), K26.5, RN2.4, RN3.4
RE3B: IC5.13 (OUT6), K26.6, RN1.4, RN4.4
RE4A: IC5.11 (OUT7), K101.8 (-), K102.1 (+), RN2.5, RN3.5
RE4B: IC5.10 (OUT8), K101.1 (+), K102.8 (-), RN1.5, RN4.5
RST: IC3.1 (PC6(PCINT14/RESET)), K19.5, R113.P$1 (1)
RXD: IC3.2 (PD0(PCINT16/RXD)), IC105.2 (OUTA), R6.P$1 (1)
SCK: IC3.19 (PB5(SCK/PCINT5)), IC5.6 (CLK), K19.4, K25.5
SCL: IC3.28 (PC5(ADC5/PCINT13)), IC100.3 (SCL1), IC104.3 (SCL1), R124.P$1 (1)
SDA: IC3.27 (PC4(ADC4/PCINT12)), IC100.2 (SDA1), IC104.2 (SDA1), R125.P$1 (1)
SS: IC3.16 (PB2(SS/OC1B/PCINT2)), IC5.4 (CS), K25.2
TXD: IC3.3 (PD1(PCINT17/TXD)), R133.P$1 (1)
VOUT+: C155.1, L2.1, PSU1.4 (VOUT+)
VOUT-: C145.2, L4.1, PSU2.6 (VOUT-)

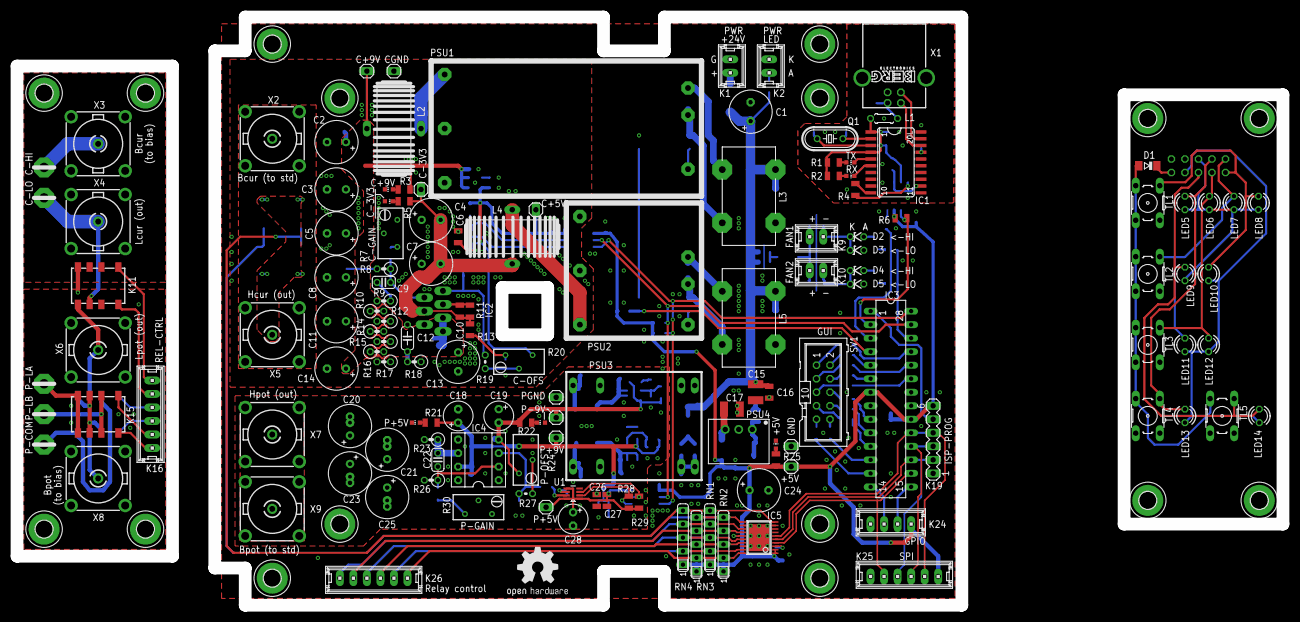
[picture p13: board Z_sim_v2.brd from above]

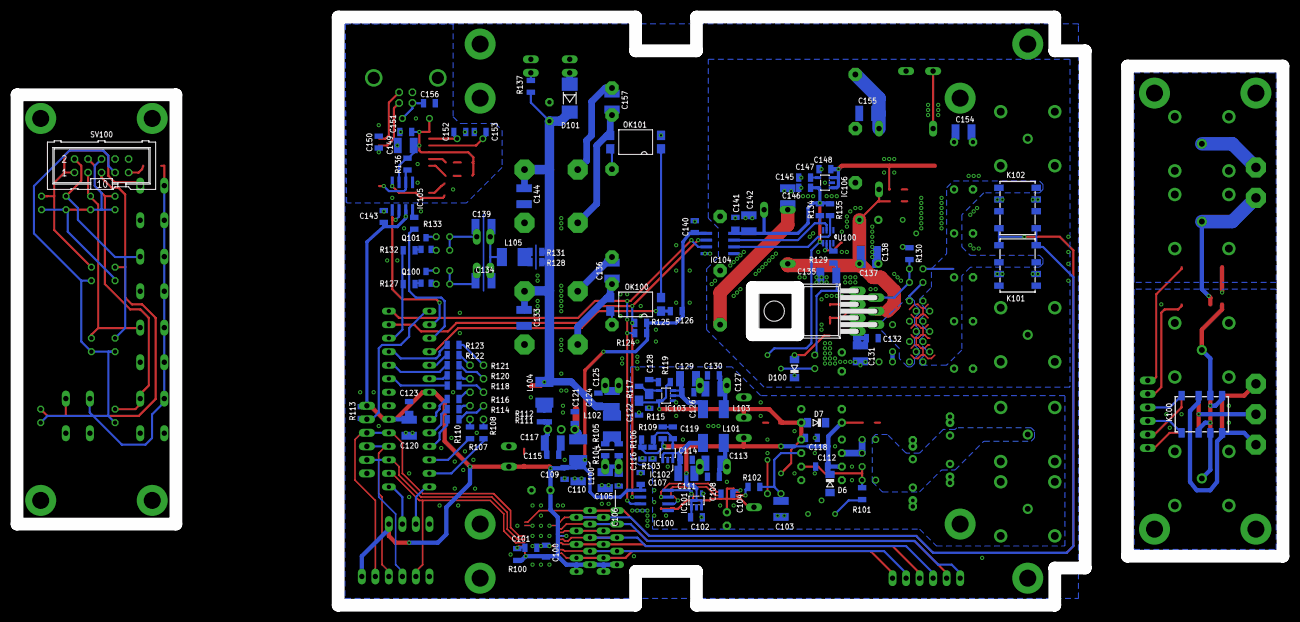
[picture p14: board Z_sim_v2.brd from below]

Board: 2 copper layers, 140.3 x 110.5 mm, 280 parts (122 on the bottom side), 159 nets.

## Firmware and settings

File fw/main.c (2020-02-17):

// Part of ZSIM - Reactance Simulator using Mutual Inductors. 
// Firmware for AVR controller of the simulator.
//
// Target MCU: ATmega88
// Fuse bits: use default setup: RC oscillator and /8 divider (1MHz)
//            If bootloader is used, refer to bootloader code.
//
// (c) 2020, Stanislav Maslan, CMI, smaslan@cmi.cz, s.maslan@seznam.cz
// The code is distributed under MIT license, https://opensource.org/licenses/MIT. 
//
// Simulator details: 
//   https://github.com/smaslan/Z-sim-mutual
//
// This project was co-developed in scope of EMPIR project LiBforSecUse
// "Lithium Batteries for Second Life Applications". Project url:
//   https://www.ptb.de/empir2018/libforsecuse/home/

#include <avr/pgmspace.h>
#include <avr/io.h>
#include <avr/interrupt.h>
#include <avr/wdt.h>
#include <avr/boot.h>
#include <util/atomic.h>
#include <util/delay_basic.h>
#include <util/delay.h>
#include <util/twi.h>
#include <string.h>
#include <stdio.h>
#include <stdlib.h>

#include "main.h"
#include "serial.h"


// power bias control (active low)
#define PBIASp PORTD
#define PBIASd DDRD
#define PBIAS PD2

// FAN control
#define PFANp PORTC
#define PFANd DDRC
#define PFAN PC3

// main timer tick [s]
#define MTICK 500e-6

// control states
typedef struct{
	int8_t bias;
	uint8_t ind;
	uint8_t range;
	uint8_t com;
	uint8_t power;
	uint16_t bias_pwr;
	uint16_t bias_pot;
}TCTRL;
volatile TCTRL ctrl;


// --- jump to bootloader ---
#define boot_start(boot_addr) {goto *boot_addr;}

//----------------------------------------------------------------------------------
// special function bistable relays controled via MAX4820
//----------------------------------------------------------------------------------

// special relays state variable
volatile uint8_t specr;

// special relays flags in status variable
#define RE_RNG 0 // range
#define RE_POL 1 // polarity
#define RE_COM 2 // common grounds bypass
#define RE_PWR 3 // power bypass relay
#define REMODF 7 // command in progress flag (do not change manually!)

// default special relays state
#define RES_DEF (0)

// special relay pulse length in ticks count (2ms should be enough)
#define RESLEN ((uint8_t)(2e-3/MTICK))

// update special relays state (states: new flag states, mask: 0's to inhibit state change)
// call this to initiate transition (IRQ must be enabled!)
void spec_relay_update(uint8_t states,uint8_t mask)
{
	uint8_t temp = specr;

	// update relay flags
	temp &= ~mask;
	temp |= (states & mask) | (1<<REMODF);
	
	// store to state variable
	specr = temp;
}


// SPI bus states
#define SPID DDRB
#define SPIP PORTB
#define SS PB2
#define SCK PB5
#define MOSI PB3

// send special relays MAX4820 controler command via SPI
void spec_relay_set(uint8_t data)
{
	// CS active
	cbi(SPIP,SS);
	
	// send data
	SPDR = data;
	
	// wait for transfer done
	while(!bit_is_set(SPSR,SPIF));

	// disable CS
	sbi(SPIP,SS);
}

// initialize special relays MAX4820 controler (SPI bus)
void spec_relay_init(void)
{
	// set SPI pin directions
	sbi(SPID,SS);
	sbi(SPID,SCK);
	sbi(SPID,MOSI);

	// enable SPI at full speed
	SPCR = (1<<SPE)|(0<<DORD)|(1<<MSTR)|(0<<CPOL)|(0<<CPHA)|(0<<SPR0);
	SPSR |= (1<<SPI2X);

	// chip select to inactive
	sbi(SPIP,SS);

	// all drivers to idle state
	spec_relay_set(0x00);
}
// relay decoder table (state flags to control pulses for MAX4820)
const uint8_t srdec_lut[] PROGMEM = {0x55,0x56,0x59,0x5A,0x65,0x66,0x69,0x6A,0x95,0x96,0x99,0x9A,0xA5,0xA6,0xA9,0xAA};

// generate MAX4820 control pulse defined by low nibble bits of 'states'
void spec_relay_generate_pulse(uint8_t states)
{
	// start pulse
	spec_relay_set(pgm_read_byte(&srdec_lut[states&0x0Fu]));
}

// initiate assynchronous update of relay states (ISR must be enabled!)
//   optionally wait for completion of the command
//   always waits for completion of previous command@
void set_relays(volatile TCTRL *ctrl,uint8_t wait)
{
	// wait for previous command to end
	while(bit_is_set(specr,REMODF));

	// make new command
	specr = ((!ctrl->ind)<<RE_POL) | (ctrl->range<<RE_RNG) | ((!ctrl->com)<<RE_COM) | (ctrl->power<<RE_PWR) | (1<<REMODF);

	// optional wait for completion
	if(wait)
		while(bit_is_set(specr,REMODF));
		
}

// sequencer that generates control pulses for the spec function relays
//   note: this must be called periodically with MTICK period
void spec_rel_tick(void)
{
	static uint8_t spec_rel = 0x00; // local state variable for the relay control
	static uint8_t spec_rel_cnt = 0; // relay control timing counter
	
	if(!spec_rel_cnt && bit_is_set(specr,REMODF) && !bit_is_set(spec_rel,REMODF))
	{
		// --- user command to change relay states found:
		
		// store desired new states
		spec_rel = specr;

		// start control pulse timer
		spec_rel_cnt = RESLEN;
				
		// start control pulse
		spec_relay_generate_pulse(spec_rel);
		
	}
	else if(!spec_rel_cnt && bit_is_set(spec_rel,REMODF))
	{
		// --- relay pulse end reached:
		
		// clear modified flag in local state variable
		cbi(spec_rel,REMODF);

		// clear modified flag in user command states variable (indicates the command is done)
		cbi(specr,REMODF);

		// end control pulse
		spec_relay_set(0x00);

	}
	else if(spec_rel_cnt > 0)
		spec_rel_cnt--;
}



//----------------------------------------------------------------------------------
// main tick timer
//----------------------------------------------------------------------------------

// button commons
#define MB0p PORTD
#define MB0d DDRD
#define MB0  PD7
#define MB1p PORTD
#define MB1d DDRD
#define MB1  PD6
// LED cathodes
#define ML0p PORTB
#define ML0d DDRB
#define ML0  PB6
#define ML1p PORTD
#define ML1d DDRD
#define ML1  PD5
#define ML2p PORTB
#define ML2d DDRB
#define ML2  PB7
// LED anodes/buttons
#define MD0p PORTC
#define MD0i PINC
#define MD0d DDRC
#define MD0  PC2
#define MD1p PORTD
#define MD1i PIND
#define MD1d DDRD
#define MD1  PD3
#define MD2p PORTC
#define MD2i PINC
#define MD2d DDRC
#define MD2  PC1
#define MD3p PORTD
#define MD3i PIND
#define MD3d DDRD
#define MD3  PD4
#define MD4p PORTC
#define MD4i PINC
#define MD4d DDRC
#define MD4  PC0

#define LED_CYCLES 1
#define LED_DEADTIME 5


// --- TIMEOUT STUFF ---
// timeout timer [ms]
volatile uint16_t timeout = 0;
// set mew timeout value
void timeout_set(uint16_t time_ms)
{
	ATOMIC_BLOCK(ATOMIC_RESTORESTATE)
	{
		// set new time
		timeout = time_ms;		
	}	
}
// check if timeout is done
uint8_t timeout_done(void)
{
	uint8_t done;
	ATOMIC_BLOCK(ATOMIC_RESTORESTATE)
	{
		// set new time
		done = (timeout == 0);
	}	
	return(done);
}



// button states
volatile uint8_t btns = 0x00;
volatile uint8_t btns_down = 0x00;

// tick ISR
ISR(TIMER0_COMPA_vect)
{
	
	static uint8_t mux_cycle = 0;
	static uint8_t btns_old = 0x00;

	if(mux_cycle == 0)
	{
		// --- button B0:

		// change mux states
		cbi(MD0d,MD0);	// mux port to inputs
		cbi(MD1d,MD1);
		cbi(MD2d,MD2);
		cbi(MD3d,MD3);
		cbi(MD4d,MD4);
		
		sbi(MD0p,MD0);	// mux port pullups
		sbi(MD1p,MD1);
		sbi(MD2p,MD2);
		sbi(MD3p,MD3);
		sbi(MD4p,MD4);

		sbi(ML1p,ML1);	// clear LEDs
		cbi(MB0p,MB0);  // set B0

	}
	else if(mux_cycle == 1)
	{
		// --- button B1:

		// read B0 states to button state variable
		uint8_t tmp = btns;
		bcopy(tmp,0,MD0i,MD0);
		bcopy(tmp,1,MD1i,MD1);
		bcopy(tmp,2,MD2i,MD2);
		bcopy(tmp,3,MD3i,MD3);
		bcopy(tmp,4,MD4i,MD4);
		btns = tmp;

		// change mux states
		sbi(MB0p,MB0);	// clear B0
		cbi(MB1p,MB1);  // set B1

	}
	else if(mux_cycle == 2+LED_DEADTIME)
	{
		// --- LED0 common:

		// read B1 states to button state variable
		uint8_t tmp = btns;
		bcopy(tmp,5,MD0i,MD0);
		bcopy(tmp,6,MD1i,MD1);
		bcopy(tmp,7,MD2i,MD2);
		btns = tmp;

		// change mux states
		sbi(MB1p,MB1);	// clear B1
		sbi(MD0d,MD0);	// mux port to outputs
		sbi(MD1d,MD1);
		sbi(MD2d,MD2);
		sbi(MD3d,MD3);
		sbi(MD4d,MD4);

		// set LEDs
		cbi(MD3p,MD3);
		cbi(MD2p,MD2);
		cbi(MD1p,MD1);
		cbi(MD0p,MD0);			
		if(ctrl.bias == 0)
		{
			// bias A
			sbi(MD3p,MD3);
		}
		else if(ctrl.bias == 1)
		{
			// bias B
			sbi(MD2p,MD2);
		}
		else if(ctrl.bias == 2)
		{
			// bias C
			sbi(MD1p,MD1);
		}
		else if(ctrl.bias == 3)
		{
			// bias D
			sbi(MD0p,MD0);			
		}
		else
		{
			// custom bias
			sbi(MD3p,MD3);
			sbi(MD0p,MD0);
		}
		// range LED A
		bcopy_v(MD4p,MD4, (!ctrl.range), 0);

		// change mux states
		cbi(ML0p,ML0);  // set L0

	}
	else if(mux_cycle == 2 + LED_DEADTIME + LED_CYCLES)
	{
		// --- LED1 common:

		// change mux states
		sbi(ML0p,ML0);	// clear L0
		
		// range LED B
		bcopy_v(MD0p,MD0, ctrl.range, 0);
		// inductive mode
		bcopy_v(MD1p,MD1, !ctrl.ind, 0);
		bcopy_v(MD2p,MD2,  ctrl.ind, 0);
		// volt-curr joint
		bcopy_v(MD3p,MD3, ctrl.com, 0);
		// power bias active
		bcopy_v(MD4p,MD4, ctrl.power, 0);
		

		// change mux states
		cbi(ML1p,ML1);  // set L1

	}
	
	mux_cycle++;	// next cycle
	if(mux_cycle >= 2 + LED_DEADTIME + LED_CYCLES*2)
	{
		mux_cycle = 0;	// mux done

		// detect button down events
		btns_down |= ((btns^btns_old)&(~btns));
		
		// store old button states
		btns_old = btns;
	}


	// --- latching relays sequencer ---
	spec_rel_tick();

	
	// --- update timeout timer ---
	static uint8_t time_div = 0;	
	time_div++;
	if(time_div >= (uint8_t)(1e-3/MTICK))
	{
		// timeout timer tick (1ms)
		time_div = 0;
		if(timeout)
			timeout--;
	}
}


//----------------------------------------------------------------------------------
// I2C STUFF
//----------------------------------------------------------------------------------

#define i2c_start() TWCR = (1<<TWINT) | (1<<TWSTA) | (1<<TWEN)
#define i2c_stop() TWCR = (1<<TWINT) | (1<<TWEN) | (1<<TWSTO)
#define i2c_data_out(data)	TWDR = (data); TWCR = (1<<TWINT) | (1<<TWEN)

// wait for I2C state change with timout (ISR must be enabled!)
uint8_t i2c_wait(uint16_t timeout_ms)
{
	if(timeout_ms)
	{
		// timeout mode
		timeout_set(timeout_ms);	
		while(!bit_is_set(TWCR,TWINT) && !timeout_done());
		return(timeout_done());
	}
	else
		while(!bit_is_set(TWCR,TWINT)); // no timeout mode

	return(0);
}

// I2C write routine with timeouts (ISR must be enabled)
uint8_t i2c_write_data(uint8_t address,uint8_t *data,uint8_t count,uint16_t timeout_ms)
{
	// start
	i2c_start();	
	if(i2c_wait(timeout_ms))
	{
		// timeout
		i2c_stop();
		return(1);
	}	
	if((TW_STATUS) != TW_START)
	{
		i2c_stop();
		return(1);
	}

	// send address + write
	i2c_data_out(address<<1);
	if(i2c_wait(timeout_ms))
	{
		// timeout
		i2c_stop();
		return(2);
	}	
	if((TW_STATUS) != TW_MT_SLA_ACK)
	{
		i2c_stop();
		return(2);		
	}

	// transmit data bytes
	for(uint8_t k = 0;k < count;k++) 
	{
		// send byte
		i2c_data_out(data[k]);
		if(i2c_wait(timeout_ms))		
		{
			// timeout
			i2c_stop();
			return(3);
		}		
		if((TW_STATUS) != TW_MT_DATA_ACK)
		{
			i2c_stop();
			return(3);			
		}
	}

	// stop
	i2c_stop();

	
	return(0);
}

// timeout in case I2C fails [ms]
#define I2C_TIMEOUT 3000

// initialization of DAC
uint8_t LTC2631_init(uint8_t address)
{
	uint8_t data[3] = {0,0,0};
	data[0] = 0x60;
	return(i2c_write_data(address, data, 3, I2C_TIMEOUT));
}

// set DAC value
uint8_t LTC2631_set(uint8_t address, uint16_t value)
{
	uint8_t data[3];

	// build command
	data[0] = 0x30;	// write and set
	data[1] = (uint8_t)(value>>4);
	data[2] = (uint8_t)((value<<4)&0x00F0u);
	
	// send it
	return(i2c_write_data(address, data, 3, I2C_TIMEOUT));
}


//----------------------------------------------------------------------------------
// MAIN
//----------------------------------------------------------------------------------

// I2C clock rate
#define I2C_FREQ 10000.0
#define I2C_ADDR_PWR 0x10
#define I2C_ADDR_POT 0x12

// button flags in edge event register
#define BTN_BIAS 0
#define BTN_RANGE 1
#define BTN_IND 2
#define BTN_COM 3
#define BTN_POWER 4

// GUI and REMOTE command flags
#define CMD_RELAYS 0 // modify relays
#define CMD_POT 1 // modify potential DAC
#define CMD_PWR 2 // modify power DAC
#define CMD_PWR_WAIT 3 // wait for power DAC response
#define CMD_ACK 4 // send remote command ACK after command executed


int main(void)
{
	// disable WDT if enabled (sometimes it fucks up ...)
	MCUSR = 0;
  	wdt_disable();

	// disable all ports
	DDRB = 0x00;
	DDRC = 0x00;
	DDRD = 0x00;

	// enable MUX common lines
	sbi(MB0d,MB0);
	sbi(MB1d,MB1);
	sbi(ML0d,ML0);
	sbi(ML1d,ML1);

	// power bias state
	sbi(PBIASd,PBIAS);
	sbi(PBIASp,PBIAS);

	// FAN to LOW
	sbi(PFANd,PFAN);
	cbi(PFANp,PFAN);
	
	// timer 0 tick
	TCCR0A = (2<<WGM00);
	TCCR0B = (2<<CS00);
	OCR0A = (uint8_t)(F_CPU/8.0*MTICK) - 1;
	TIMSK0 |= (1<<OCIE0A);

	// I2C as master
	TWCR = (1<<TWEN)|(1<<TWEA);
	TWBR = (uint8_t)((F_CPU - 16.0*I2C_FREQ)/(2.0*I2C_FREQ));
	TWSR = (0<<TWPS0);
	PORTC |= (1<<PC4) | (1<<PC5);

	// clear states
	ctrl.bias = 0;
	ctrl.ind = 0;
	ctrl.range = 0;
	ctrl.com = 0;
	ctrl.power = 0;
	ctrl.bias_pwr = 0;
	ctrl.bias_pot = 0;

	// init UART
	serial_init();

	// init SPI for relay driver
	spec_relay_init();
		
	// enable ISR
	sei();

	// put relays to default state
	set_relays(&ctrl,1);
	
	// default voltage set
	#define u2dac(voltage) ((uint16_t)(4095.0*voltage/5.0))
	uint16_t volts[4] = {u2dac(0.0), u2dac(3.0), u2dac(4.0), u2dac(5.0)};


	while(1)
	{

		// HW setup modified flags
		uint8_t modf = 0;
		
		
		// --- BUTTON PROCESSING ---
		// get and clear button event flags (this should be atomic)
		uint8_t flags;
		ATOMIC_BLOCK(ATOMIC_FORCEON)
		{
			flags = btns_down;
			btns_down = 0x00;
		}


		if(bit_is_set(flags,BTN_BIAS))
		{
			// cycle predefined bias levels
			ctrl.bias++;
			if(ctrl.bias > 3)
				ctrl.bias = 0;	

			// set mew voltages
			ctrl.bias_pot = volts[ctrl.bias];
			ctrl.bias_pwr = ctrl.bias_pot;
									
			modf |= (1<<CMD_POT) | (1<<CMD_PWR);
		}
		else if(bit_is_set(flags,BTN_RANGE))
		{
			// cycle ranges
			ctrl.range++;
			if(ctrl.range > 1)
				ctrl.range = 0;

			sbi(modf,CMD_RELAYS);
			
		}
		else if(bit_is_set(flags,BTN_IND))
		{
			// toggle polarity
			ctrl.ind++;
			if(ctrl.ind > 1)
				ctrl.ind = 0;

			sbi(modf,CMD_RELAYS);
		}
		else if(bit_is_set(flags,BTN_COM))
		{
			// toggle pot-cur joint switch
			ctrl.com++;
			if(ctrl.com > 1)
				ctrl.com = 0;

			sbi(modf,CMD_RELAYS);
		}
		else if(bit_is_set(flags,BTN_POWER))
		{
			// toggle current path bias source
			ctrl.power++;
			if(ctrl.power > 1)
				ctrl.power = 0;	

			if(ctrl.power)
			{
				// power was just turned on - wait for actual power up				
				modf |= (1<<CMD_PWR) | (1<<CMD_PWR_WAIT);
			}
			sbi(modf,CMD_RELAYS);
		}

		// --- REMOTE PROCESSING ---
		char cmdbuf[RX_BUF_SZ]; // local command buffer
		char *par;
		if(serial_decode(cmdbuf,&par))
		{
			// --- command detected ---

			if(!strcmp_P(cmdbuf,PSTR("MODE")))
			{
				// "MODE mode" to set polarity of potential to "mode"

				if(!par)
					serial_error(SCPI_ERR_tooFewParameters,NULL,SCPI_ERR_STORE); // missing parameter
				else if(!strcmp_P(par,PSTR("IND")))
					ctrl.ind = 1;
				else if(!strcmp_P(par,PSTR("CAP")))
					ctrl.ind = 0;
				else
					serial_error(SCPI_ERR_wrongParamType,PSTR(" Only IND or CAP supported."),SCPI_ERR_STORE); // invalid

				sbi(modf,CMD_RELAYS);

			}
			else if(!strcmp_P(cmdbuf,PSTR("RANGE")))
			{
				// "RANGE range" to set range (1 or 2)

				if(!par)
					serial_error(SCPI_ERR_tooFewParameters,NULL,SCPI_ERR_STORE); // missing parameter
				else
				{
					uint8_t val = atoi(par);
					if(val < 1 || val > 2)
						serial_error(SCPI_ERR_wrongParamType,PSTR(" Only ranges 1 and 2 supported."),SCPI_ERR_STORE); // invalid
					else
						ctrl.range = val - 1;

					sbi(modf,CMD_RELAYS);
				}
					
			}
			else if(!strcmp_P(cmdbuf,PSTR("COMMON:STATE")))
			{
				// "COMMON:STATE state" to set potential and bias grounds connections (0/1)

				if(!par)
					serial_error(SCPI_ERR_tooFewParameters,NULL,SCPI_ERR_STORE); // missing parameter
				else
				{
					if(!strcmp_P(par,PSTR("ON")) || !strcmp_P(par,PSTR("1")))
						ctrl.com = 1;
					else if(!strcmp_P(par,PSTR("OFF")) || !strcmp_P(par,PSTR("0")))
						ctrl.com = 0;
					else
						serial_error(SCPI_ERR_wrongParamType,PSTR(" Only ON/OFF or 1/0 supported."),SCPI_ERR_STORE); // invalid

					sbi(modf,CMD_RELAYS);
				}
			}
			else if(!strcmp_P(cmdbuf,PSTR("POWER:STATE")))
			{
				// "POWER:STATE state" to set enable state of power bias

				if(!par)
					serial_error(SCPI_ERR_tooFewParameters,NULL,SCPI_ERR_STORE); // missing parameter
				else
				{
					if(!strcmp_P(par,PSTR("ON")) || !strcmp_P(par,PSTR("1")))
						ctrl.power = 1;
					else if(!strcmp_P(par,PSTR("OFF")) || !strcmp_P(par,PSTR("0")))
						ctrl.power = 0;
					else
						serial_error(SCPI_ERR_wrongParamType,PSTR(" Only ON/OFF or 1/0 supported."),SCPI_ERR_STORE); // invalid

					if(ctrl.power)
					{
						// power was just turned on - wait for actual power up				
						sbi(modf,CMD_PWR);
						sbi(modf,CMD_PWR_WAIT);
					}					
					
					sbi(modf,CMD_RELAYS);
				}
			}
			else if(!strcmp_P(cmdbuf,PSTR("BIAS:VOLT")))
			{
				// "BIAS:VOLT level" to set bias voltage in [mV]
				// this sets the same bias to both sources

				if(!par)
					serial_error(SCPI_ERR_tooFewParameters,NULL,SCPI_ERR_STORE); // missing parameter
				else
				{
					uint16_t mvlev = atol(par);
					if(mvlev > 5000)
						serial_error(SCPI_ERR_wrongParamType,PSTR(" Maximum supported level is 5000mV."),SCPI_ERR_STORE); // invalid range

					// custom bias set
					ctrl.bias = -1;
					
					// set new voltages to both sources
					ctrl.bias_pot = (uint16_t)(((uint32_t)mvlev*4095ul)/5000ul);
					ctrl.bias_pwr = ctrl.bias_pot;

					// update DAC(s)
					sbi(modf,CMD_PWR);
					sbi(modf,CMD_POT);
				}
			}
			else if(!strcmp_P(cmdbuf,PSTR("BIAS:POT:VOLT")))
			{
				// "BIAS:POT:VOLT level" to set bias voltage in [mV]
				// this sets level to potential only

				if(!par)
					serial_error(SCPI_ERR_tooFewParameters,NULL,SCPI_ERR_STORE); // missing parameter
				else
				{
					uint16_t mvlev = atol(par);
					if(mvlev > 5000)
						serial_error(SCPI_ERR_wrongParamType,PSTR(" Maximum supported level is 5000mV."),SCPI_ERR_STORE); // invalid range

					// custom bias set
					ctrl.bias = -1;
					
					// set new voltages to both sources
					ctrl.bias_pot = (uint16_t)(((uint32_t)mvlev*4095ul)/5000ul);
					
					// update DAC(s)
					sbi(modf,CMD_POT);

				}
			}
			else if(!strcmp_P(cmdbuf,PSTR("BIAS:PWR:VOLT")))
			{
				// "BIAS:PWR:VOLT level" to set bias voltage in [mV]
				// this sets level to power only

				if(!par)
					serial_error(SCPI_ERR_tooFewParameters,NULL,SCPI_ERR_STORE); // missing parameter
				else
				{
					uint16_t mvlev = atol(par);
					if(mvlev > 5000)
						serial_error(SCPI_ERR_wrongParamType,PSTR(" Maximum supported level is 5000mV."),SCPI_ERR_STORE); // invalid range

					// custom bias set
					ctrl.bias = -1;
					
					// set new voltages to both sources
					ctrl.bias_pwr = (uint16_t)(((uint32_t)mvlev*4095ul)/5000ul);
					
					// update DAC(s)
					sbi(modf,CMD_PWR);

				}
			}
			else if(!strcmp_P(cmdbuf,PSTR("FAN")))
			{
				// "FAN state" to set potential and bias grounds connections (LO/HI)

				if(!par)
					serial_error(SCPI_ERR_tooFewParameters,NULL,SCPI_ERR_STORE); // missing parameter
				else
				{
					if(!strcmp_P(par,PSTR("LO")) || !strcmp_P(par,PSTR("LOW")))
						cbi(PFANp,PFAN)
					else if(!strcmp_P(par,PSTR("HIGH")) || !strcmp_P(par,PSTR("HI")))
						sbi(PFANp,PFAN)
					else
						serial_error(SCPI_ERR_wrongParamType,PSTR(" Only LO/HI or LOW/HIGH supported."),SCPI_ERR_STORE); // invalid
				}
			}
			else if(!strcmp_P(cmdbuf,PSTR("*OPC?")))
			{
				// "*OPC?" returns "+1" when ready to execute new command
				//  note: this whole code executes in a loop, so the commands are executed
				//        before we get here again, so OPC? should always return 1 here
				serial_tx_cstr(PSTR("+1\n"));
			}
			else if(!strcmp_P(cmdbuf,PSTR("*RST")))
			{
				// *RST - restarts controller
				cli();
				//wdt_enable(WDTO_15MS);
				boot_start(0x0000ul);
				while(1);				
			}
			else if(!strcmp_P(cmdbuf,PSTR("*IDN?")))
			{
				// "*IDN?" to return IDN string
				serial_tx_cstr(PSTR("Z-Simulator Bias Source V1.1, s.n. 20200214\n"));
			}
			else if(!strcmp_P(cmdbuf,PSTR("SYST:ERR?")))
			{
				// "SYST:ERR?" return error buffer
				serial_error(SCPI_ERR_noError,NULL,SCPI_ERR_SEND);				
			}
			else if(!strcmp_P(cmdbuf,PSTR("SYST:BOOT")))
			{
				// SYST:BOOT <password> - initiates bootloader

				// send ACK/NACK
				if(par && !strcmp_P(par,PSTR("17IND10")))
				{
					// send ACK
					serial_tx_cstr(PSTR("1\n"));				

					// get extended fuse bits
					uint8_t fuex = boot_lock_fuse_bits_get(GET_EXTENDED_FUSE_BITS);

					// extract bootsize index (FUSE_BOOTSZ1:FUSE_BOOTSZ0)
					fuex = !!(fuex&(~FUSE_BOOTSZ0)) + (!!(fuex&(~FUSE_BOOTSZ1))<<1);

					// calculae bootloader start address in [Bytes]
					uint16_t addr = FLASHEND + 1 - (256ul<<(3 - fuex));
					
					// jump to boot section
					boot_start(addr);
				}
				else
					serial_tx_cstr(PSTR("0\n"));				
			}			
			else
			{
				// invalid
				serial_error(SCPI_ERR_undefinedHeader,NULL,SCPI_ERR_STORE);
			}

		}


		
		
		// --- UPDATE HW STATE ---

		// set DCDC state (no need for flags)
		bcopy_v(PBIASp,PBIAS, !ctrl.power, 0);

		// update power DAC
		if(bit_is_set(modf,CMD_PWR))
		{
			// wait for I2C ACK response - that should indicate power is up
			if(bit_is_set(modf,CMD_PWR_WAIT))
				while(LTC2631_init(I2C_ADDR_PWR) != 0);

			// set value
			LTC2631_init(I2C_ADDR_PWR);
			LTC2631_set(I2C_ADDR_PWR, ctrl.bias_pwr);
		}
		
		// update potential DAC
		if(bit_is_set(modf,CMD_POT))
		{		
			LTC2631_init(I2C_ADDR_POT);
			LTC2631_set(I2C_ADDR_POT, ctrl.bias_pot);
		}

		// update relays
		if(bit_is_set(modf,CMD_RELAYS))
			set_relays(&ctrl,1);
		
		// clear HW mod flags
		modf = 0;

	}

}

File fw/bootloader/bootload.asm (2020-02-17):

;compiler: avrasm
;Simple bootloader that should fit in 512 Bytes.
;(c) Stanislav Maslan, 2020, s.maslan@seznam.cz
;The code is distributed under MIT license, https://opensource.org/licenses/MIT. 

	.include "m88def.inc"	;ATmega168 defines
	.include "macros.asm"	;macros
		
	.equ	XTAL=1000000	;XTAL frequency [Hz]
	.equ	baud=9600	;initial uart baudrate

	.dseg
page_buff:	.byte	PAGESIZE	;page buffer


	.cseg
	.equ	MYBOOTSTART=SECONDBOOTSTART
	.org	MYBOOTSTART	;bootsector reset
	rjmp	main
	.org	MYBOOTSTART+INT_VECTORS_SIZE
	reti		;safety gap in case of random ints

	;welcome string
str_welcome:	.db	"Schmutzig Bootloader Ready!",0
	;bootloader passcode
str_passcode:	.db	"17IND10",0
	
main:	;stop WDT and ISRs just in case
	cli
	adiw	R30,0	;nop,nop
	clr	R0
	sts	mcusr,R0
	sts	wdtcsr,R0
	
	outiw	sp,RAMEND	;reset stack

	;reset ports to inputs
	out	ddrb,R0
	out	ddrc,R0
	out	ddrd,R0

	;init USART
	stsi	ucsr0a,(1<<u2x0)
	stsi	ucsr0b,(1<<rxen0)|(1<<txen0)
	stsi	ucsr0c,(3<<ucsz00)
	stsiw	ubrr0l,(XTAL/(8*baud)-1)
	
	;wait a moment
	ldi	R16,50	;long when we just booted
	rcall	Delay10ms
	
	;flush RX buffer
	lds	R16,udr0
	lds	R16,udr0
		
	ldi	R16,'B'
	rcall	UsTxChar	;send bootloader ready mark
	
	;send welcome string
	ldiw	R30,str_welcome*2
boot_welc_str:	lpm	R16,Z+
	rcall	UsTxChar
	tst	R16
	brne	boot_welc_str
	
	
	;wait up to 1s for response
	ldi	R20,10
boot_wait:	ldi	R16,100
	rcall	Delay1ms
	rjss	ucsr0a,rxc0,boot_start
	;no response yet
	dbnz	R20,boot_wait
	;timeout
app_start:	jmp	0x0000	;start application

	;start bootloader		
boot_start:	lds	R16,udr0
	cpi	R16,'R'
	brne	app_start	;leave if incorrect response
	
	ldi	R16,'A'
	rcall	UsTxChar	;send ack mark
	
	;receive passcode
	ldiw	R30,str_passcode*2	;passcode string
	ldi	R18,'A'	;status: so far ok
boot_pass_loop:	rcall	UsRxChar	;get usart char
	lpm	R17,Z+	;get passcode char
	cpse	R16,R17
	ldi	R18,'F'	;status: failed
	cpi	R16,0
	breq	boot_pass_a	;string done, passed
	cpi	R17,0	;string not done
	brne	boot_pass_loop	;passcode not done	
	;passcode compared
boot_pass_a:	mov	R16,R18
	rcall	UsTxChar	;return passcode status
	
	cpi	R16,'A'
	brne	app_start	;leave if not ack		
	
	ldi	R16,PAGESIZE
	rcall	UsTxChar	;send page size
	
	ldiw	R16,MYBOOTSTART
	rcall	UsTxWord	;send available FLASH size [B]

	ldiw	R30,0x0000	;FLASH start

	
boot_next_page:	rcall	UsRxChar
	cpi	R16,'D'
	breq	app_start	;all done - start app
	
	;receive page
	ldiw	R28,page_buff
	ldi	R24,PAGESIZE*2
boot_page_rx:	rcall	UsRxChar
	st	Y+,R16
	dbnz	R24,boot_page_rx	
		
	ldi	R16,(1<<selfprgen)|(1<<pgers)
	rcall	ExecSPM	;erase page
	
	ldi	R16,(1<<selfprgen)|(1<<rwwsre)
	rcall	ExecSPM	;re-enable RWW section	

	;write page from buffer
	ldiw	R28,page_buff	;page temp buffer
	ldi	R24,PAGESIZE
boot_data_loop:	ldw	R0,Y+
	ldi	R16,(1<<selfprgen)
	rcall	ExecSPM	;write word into buffer
	adiw	R30,2	;flash next word	
	dbnz	R24,boot_data_loop	;next word?
	subiw	R30,PAGESIZE*2	;pointer back to start of page
	 	
	ldi	R16,(1<<selfprgen)|(1<<pgwrt)
	rcall	ExecSPM	;page write

	ldi	R16,(1<<selfprgen)|(1<<rwwsre)
	rcall	ExecSPM	;re-enable RWW section
	
	;page verification
	ldi	R26,'P'	;no error
	ldiw	R28,page_buff
	ldi	R24,PAGESIZE*2	;page size in bytes
boot_verif_loop:	lpm	R0,Z+	;FLASH application dword
	ld	R1,Y+	;RAM application dword
	cpse	R0,R1	;compare
	ldi	R26,'F'	;set error flag	
	dec	R24
	brne	boot_verif_loop
	
	;verify that RWW section is safe to read
boot_wait_pge_rdy:	lds	R16,spmcsr
	sbrs	R16,rwwsb
	rjmp	boot_page_written
	ldi	R16,(1<<selfprgen)|(1<<rwwsre)
	rcall	ExecSPM
	rjmp	boot_wait_pge_rdy
boot_page_written:		
	mov	R16,R26	;page write status
	rcall	UsTxChar	;send page data request
	
	rjmp	boot_next_page	;next page


;------------------------------------------------------------------------------------------
;	execute SPM instruction
;------------------------------------------------------------------------------------------
ExecSPM:	in	R17,spmcsr
	sbrc	R17,selfprgen
	rjmp	ExecSPM	;wait for complete last spm operation
	out	spmcsr,R16	;new command
	spm		;execute
	ret

;************************************************************************************************
;	Other routines
;************************************************************************************************
;------------------------------------------------------------------------------------------------
;	R16*1ms delay (0=~256ms)
;------------------------------------------------------------------------------------------------
Delay1ms:	;~1ms
	ldi	R17,XTAL/((100*3)*1000)
	;100*3 cycles
Delay1msL2:	ldi	R18,100
Delay1msL1:	dbnz	R18,Delay1msL1
	dbnz	R17,Delay1msL2
	dbnz	R16,Delay1ms	
	ret
	
;------------------------------------------------------------------------------------------------
;	R16*10ms delay (0=~2.56s)
;------------------------------------------------------------------------------------------------
Delay10ms:	mov	R15,R16
	ldi	R16,10
	rcall	Delay1ms	;10ms delay
	dbnz	R15,PC-1-1-1
	ret
	
;************************************************************************************************
;	USART routines
;************************************************************************************************
;------------------------------------------------------------------------------------------------
;	Rx R16 char
;------------------------------------------------------------------------------------------------
UsRxChar:	lds	R16,ucsr0a
	sbrs	R16,rxc0
	rjmp	UsRxChar
	lds	R16,udr0
	ret

;------------------------------------------------------------------------------------------------
;	Tx R16 char
;------------------------------------------------------------------------------------------------
UsTxChar:	lds	R17,ucsr0a
	sbrs	R17,udre0
	rjmp	UsTxChar
	sts	udr0,R16
	ret

;------------------------------------------------------------------------------------------------
;	Tx R16 word
;------------------------------------------------------------------------------------------------
UsTxWord:	push	R17
	rcall	UsTxChar
	pop	R16
	rjmp	UsTxChar
	

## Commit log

2020-02-03 add: EAGLE data and DOC
    - possibly not final version!
    [Z_sim_v2.brd, Z_sim_v2.sch]
2021-03-22 fix: updated doc
    [Z_sim_v2.brd, Z_sim_v2.sch]
